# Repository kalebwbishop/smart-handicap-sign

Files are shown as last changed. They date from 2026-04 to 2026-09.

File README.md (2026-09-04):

# Hazard Hero

Hazard Hero is a **one-sign pilot** for accessible parking assistance. The pilot proves one simple loop:

1. A visitor waves at the installed sign.
2. The sign sends the configured sample window to the backend.
3. The backend marks the sign as `assistance_requested`.
4. A staff member sees the request in the app, acknowledges it, and resolves it.
5. The sign returns to `available`.

If a request turns out to be a false positive, the operator app can label it and the backend keeps the raw samples for later training.

If that loop works reliably for one installed sign, the pilot is successful.

## Pilot scope

### In scope

- One installed ESP32 sign
- One backend environment
- One operator account or one small pilot team
- One mobile operator workflow
- One fixed installation location
- Basic event history for request, acknowledge, and resolve actions

### Explicitly deferred

These items may exist elsewhere in the repo, but they are **not required for pilot launch**:

- Multi-org or fleet management workflows
- Rich site and parking-space administration
- Full QR/device claim operations for scaled deployment
- OTA update workflows
- Push notifications as a launch dependency
- Training-mode productization
- Old social/media/template features from earlier repo history

See `PILOT.md` for the detailed pilot definition and launch checklist.

## Pilot architecture

```text
ESP32 sign
  -> GET /api/v1/devices/{serial}/status
  -> when status == available, collect the configured ADC sample window
  -> POST /api/v1/inference/classify
  -> backend changes sign to assistance_requested when a wave is detected
  -> staff app shows the request
  -> staff acknowledges and resolves the request
```

Primary sign states for the pilot:

`available -> assistance_requested -> assistance_in_progress -> available`

## Repository layout

```text
smart-handicap-sign/
├── backend/      FastAPI API, async services, embedded inference
├── frontend/     React Native + Expo operator app
├── database/     PostgreSQL schema and migration scripts
├── firmware/     ESP-IDF firmware for the pilot sign
├── hardware/     Legacy MicroPython implementation
├── ai/           Model training code
└── PILOT.md      Pilot scope and launch checklist
```

## Quick start

### Prerequisites

- Node.js 18+
- Python 3.12 for the backend
- Docker Desktop
- PostgreSQL access via `docker compose`
- WorkOS credentials for auth

### Local setup

1. Install workspace dependencies:

   ```bash
   npm install
   ```

2. Configure environment variables:

   - `backend/.env`
   - `frontend/.env`

3. Start Postgres:

   ```bash
   npm run db:up
   ```

4. Apply the schema:

   ```bash
   npm run db:migrate
   ```

5. Run the backend:

   ```bash
   cd backend
   pip install -r requirements.txt
   uvicorn app.main:app --host 0.0.0.0 --port 8000 --reload
   ```

   To open a live matplotlib graph for every inference payload during local debugging,
   set `INFERENCE_DEBUG_PLOT_ENABLED=true` in `backend/.env` before starting the backend.

6. Run the frontend:

   ```bash
   cd frontend
   npm start
   ```

7. Flash and provision the pilot sign using `firmware/README.md`.

## Pilot operations

For the pilot, operators only need to:

1. Log in.
2. Watch the current sign status.
3. Acknowledge a new assistance request.
4. Resolve the request after helping the visitor.

Setup, manufacturing, and scale-out workflows should not be treated as launch blockers.

## Key API endpoints for the pilot

- `GET /health`
- `GET /api/v1/status`
- `GET /api/v1/devices/{serial_number}/status`
- `POST /api/v1/inference/classify`
- `POST /api/v1/devices/{serial_number}/acknowledge`
- `POST /api/v1/devices/{serial_number}/resolve`
- `POST /api/v1/devices/{serial_number}/events/{device_event_id}/false-positive`

## Validation

Useful repo commands for the pilot:

```bash
# Backend tests
cd backend
pytest

# Frontend lint
npm run lint --workspace=frontend

# Frontend tests (placeholder suite)
npm run test --workspace=frontend
```

Firmware validation depends on an ESP-IDF 5.4+ environment; see `firmware/README.md` and `firmware/TEST_PLAN.md`.

## Related docs

- `PILOT.md` - pilot definition and launch checklist
- `firmware/README.md` - flash, configure, and operate the pilot sign
- `firmware/TEST_PLAN.md` - hardware validation checklist for the pilot sign
- `WORKOS_SETUP.md` - auth provider setup

## Status

This repository still contains some post-pilot or legacy building blocks. When documentation and implementation disagree, treat the **one-sign pilot flow** as the current product target.

{
  "SchemaVersion": "1.0",
  "MessageId": "a4f2c8d1-6b73-4e95-9a20-1c5d7f8b3e42",
  "OccurredAt": "2026-09-02T20:20:00Z",
  "DeviceId": "SHS-2605-S01-A7K-00001-J",
  "Classification": {
    "Label": "positive",
    "Confidence": 0.97
  }
}

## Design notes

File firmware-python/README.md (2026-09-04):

## WS2812B LED test

This MicroPython test drives a 38-pixel WS2812B strip from an ESP32. It
alternates between solid green and off, holding each state for five seconds.

Default configuration:

- `LED_DATA_PINS`: usable output GPIOs tested one at a time
- `NUM_LEDS`: 38
- `BRIGHTNESS`: 128
- Color order: RGB values passed to MicroPython's `neopixel` driver

Copy `main.py` to the ESP32 as the runtime entry point. Connect the strip's
regulated 5 V and GND to the buck converter, connect ESP32 GND to the same
ground, and route the strip's `DIN` through a 330-470 ohm resistor to the GPIO currently
being tested. The firmware clears every strip before lighting the current pin.
A 1000 uF capacitor across the strip supply is recommended.

### Run on an ESP32

Install the host tools:

```powershell
python -m pip install esptool mpremote
```

Find the board's serial port in Windows Device Manager, then replace `COM3`
below if needed. For a fresh ESP32, download the generic firmware from
<https://micropython.org/download/ESP32_GENERIC/> and flash it:

```powershell
python -m esptool --port COM3 chip-id
python -m esptool --port COM3 erase-flash
python -m esptool --port COM3 --baud 460800 write-flash 0x1000 ESP32_GENERIC.bin
```

Copy the test to the board and restart it:

```powershell
python -m mpremote connect COM3 fs cp .\main.py :main.py
python -m mpremote connect COM3 reset
python -m mpremote connect COM3 repl
```

The test starts automatically after reset. Verify the deployed file with:

```powershell
python -m mpremote connect COM3 fs sha256sum :main.py
```
python -m mpremote connect COM3 fs cp .\main.py :main.py && python -m mpremote connect COM3 reset && python -m mpremote connect COM3 repl

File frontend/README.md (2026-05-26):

# frontend_new

This directory contains the new frontend monorepo structure for Hazard Hero.  
It separates mobile and web apps while sharing reusable code through workspace packages.

## Why `frontend_new` exists

`frontend_new` is an incremental migration target so we can:

1. Keep the old frontend flow untouched while migration is in progress.
2. Split platform apps cleanly (`apps/mobile`, `apps/web`).
3. Extract shared logic into packages (`packages/shared`, `packages/ui`).

## Directory layout

```text
frontend_new/
  apps/
    mobile/      # Expo React Native app
    web/         # Next.js web app
  packages/
    shared/      # shared types, API helpers, config utilities
    ui/          # shared UI package (scaffolded)
    eslint-config/
    tsconfig/
  package.json
  pnpm-workspace.yaml
  turbo.json
  tsconfig.base.json
```

## pnpm in this repo

This monorepo uses **pnpm workspaces**.

- Workspace manifest: `frontend_new/pnpm-workspace.yaml`
- Root package manager pin: `frontend_new/package.json` (`packageManager`)
- Cross-package deps use `workspace:*` (example: `@hazard-hero/shared`)

### Install dependencies

From `frontend_new`:

```bash
pnpm install
```

### Run apps

From `frontend_new`:

```bash
# Run all dev tasks via turbo
pnpm dev

# Run only mobile
pnpm dev:mobile

# Run only web
pnpm dev:web
```

### Useful workspace commands

```bash
# Typecheck all packages/apps through turbo
pnpm typecheck

# Run a command for one workspace package
pnpm --filter mobile lint
pnpm --filter web build
pnpm --filter @hazard-hero/shared typecheck
```

## Notes

- Run commands from inside `frontend_new` so pnpm resolves the workspace correctly.
- `apps/mobile` and `apps/web` can import from `packages/*`.
- `packages/*` must not import from `apps/*`.

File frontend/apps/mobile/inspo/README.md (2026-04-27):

# Composio Inspired Design System

[DESIGN.md](https://github.com/VoltAgent/awesome-design-md/blob/main/design-md/composio/DESIGN.md) extracted from the public [Composio](https://composio.dev/) website. This is not the official design system. Colors, fonts, and spacing may not be 100% accurate. But it's a good starting point for building something similar.

## Files

| File | Description |
|---|---|
| `DESIGN.md` | Complete design system documentation (9 sections) |
| `preview.html` | Interactive design token catalog (light) |
| `preview-dark.html` | Interactive design token catalog (dark) |

Use [DESIGN.md](https://github.com/VoltAgent/awesome-design-md/blob/main/design-md/composio/DESIGN.md) to use as a reference for AI agents (Claude, Cursor, Stitch) to generate UI that looks like the Composio design language.

## Preview

A sample landing page built with DESIGN.md. It shows the actual colors, typography, buttons, cards, spacing, and elevation, all in one page.

### Dark Mode
Composio Design System — Dark Mode

### Light Mode
Composio Design System — Light Mode

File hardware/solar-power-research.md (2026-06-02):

# Solar Power Feasibility Research - Hazard Hero Sign Node

> **Directory note:** The `hardware/` directory is legacy-designated in this repository; the
> active embedded implementation lives in `firmware/`. This document is placed here
> intentionally because it is most naturally read alongside the PCB design artifacts
> (`hazard-hero-easyeda-pcb.json`, `hazard-hero-pcb-README.md`) and the legacy MicroPython
> files (`main.py`, `config.py`, etc.) that preceded the current C firmware. All firmware
> citations reference the active ESP-IDF C codebase under `firmware/main/`.

---

## Executive Summary

The Hazard Hero sign node is presently designed for a hardwired **12 V DC** field supply. The
PCB includes a reserved battery header (J2/VBAT) but no charge controller, no power-path
management IC, and no battery management subsystem. The active firmware runs the ESP32-WROOM-32
at a fixed **240 MHz** with Wi-Fi continuously associated and no power management enabled - a
configuration optimized for deterministic latency, not energy efficiency.

The controller alone draws roughly **80-120 mA at 3.3 V** in the steady-state sampling loop,
before the sign or lamp load switched by Q1 is considered. Because that lamp load is
**not characterized anywhere in the repository**, any specific panel-watt or battery-Ah figure
would carry an order-of-magnitude uncertainty and is intentionally avoided in this document.
Rough sizing formulas are provided so the work can be completed once the lamp load is measured.

Solar operation is technically achievable on this platform, but it requires changes at every
layer: new PCB hardware (charge controller, power-path IC, battery connector), a redesigned
power entry section, firmware power-management strategy (DFS, modem-sleep, and graceful
offline behavior), and an enclosure-level survey for panel placement and thermal management.
None of these are present today. This document maps each gap, estimates the scope of work, and
identifies the highest-risk items to resolve before committing to a solar build.

---

## 1. Current Architecture Overview

### 1.1 PCB power chain

The Hazard Hero controller board (`hardware/hazard-hero-pcb-README.md`) implements a
straightforward cascade:[^pcb-flow]

```
J1 (12 V IN)
  -> F1 (PTC resettable fuse / current limit)
  -> D1 (TVS transient clamp)
  -> U1 (external 5 V buck module header)
  -> U2 (3.3 V SOT-223 LDO)
  -> U3 (ESP32 controller module)
```

The sign or lamp load is fed from the fused 12 V rail through J3 (`VIN_FUSED` / `LAMP_RET`)
and switched on the low side by the Q1 DPAK MOSFET. The load topology means Q1 carries the
full lamp current referenced to GND, while the supply side of the lamp sees the protected
12 V rail directly.

**J2 (VBAT)** is a reserved 2-pin terminal. The PCB README states explicitly: *"The current
layout does not yet include a full charger or power-path management circuit around it."*[^j2-vbat]
It is a provision point, not a functional battery subsystem.

### 1.2 Active firmware at a glance

| Item | Value | Source |
|---|---|---|
| Target module | ESP32-WROOM-32 (4 MB flash, no PSRAM) | `firmware/sdkconfig.defaults:2` (comment), `firmware/README.md:9` |
| CPU clock | **240 MHz, fixed** | `firmware/sdkconfig.defaults:10` |
| ADC batch size | **configured sample window** | `firmware/main/adc_sampler.h:10` |
| Sample interval | **configured interval** | `firmware/main/adc_sampler.h:11`, comment line 22 |
| Status poll interval | **3 s** (non-`available` states) | `firmware/main/main.c:25` |
| Post-classify inter-loop delay | **1 s** | `firmware/main/main.c:24` |
| Watchdog timeout | **30 s** | `firmware/sdkconfig.defaults:28` |
| Wi-Fi mode | STA, always-on | `firmware/main/wifi_manager.c` |
| Wi-Fi power saving | **None configured** | No `esp_wifi_set_ps()` call in codebase |
| ESP-IDF power management | **Not enabled** | `CONFIG_PM_ENABLE` absent from `firmware/sdkconfig.defaults` |

Main loop cycle when the device is in `available` state:[^main-loop]

```
poll GET /devices/{serial}/status
  -> if not available -> wait 3 s, loop
  -> if available:
       collect the configured ADC sample batch   (CPU mostly idle, Wi-Fi held live)
       POST /inference/classify
       wait 1 s
       loop
```

During the ADC window, the Wi-Fi association is maintained but no data is transmitted.
The CPU spends the vast majority of this window blocked inside `vTaskDelay(pdMS_TO_TICKS(25))`
between samples - idle time that power management could exploit if enabled.[^adc-loop]

### 1.3 Legacy MicroPython context

The `hardware/` directory contains legacy MicroPython files (`main.py`, `config.py`,
`led.py`, `provision.py`, `sensor.py`, `identity.py`, `wifi_utils.py`) that preceded the
current ESP-IDF C implementation. The firmware README explicitly states the C firmware
"replaces the legacy MicroPython runtime in `hardware/`".[^fw-readme] Those Python files are
historical artifacts; they are not executed by any active hardware.

---

## 2. What Would Need to Be Added for Solar Power

### 2.1 Solar input and charge regulation

No solar charging circuit exists on the current PCB. A production-grade addition requires at
minimum the following components, none of which are present:

1. **MPPT solar charge controller IC** - sits between the solar panel and the battery,
   maximizing panel power extraction while protecting the battery from overcharge and
   providing a stable output bus. Examples: Texas Instruments BQ24650 (lead-acid / LiFePO4
   compatible), CN3791 (simpler MPPT, single-cell lithium), or a module-level solution such
   as a Victron SmartSolar unit for higher powers.

2. **Battery pack** - a chemistry chosen for the outdoor temperature range. LiFePO4 (lithium
   iron phosphate) is strongly preferred for field use: better cycle life, flatter discharge
   curve, and safer thermal behavior than NMC/NCA. It requires a chemistry-appropriate
   charger and cell-level BMS (battery management system) for overdischarge protection.
   Sealed lead-acid (SLA / AGM) is a lower-cost alternative with lower energy density and
   more stringent temperature derating.

3. **Power-path / load switch** - a circuit that routes power from solar/battery to the
   system, prevents the battery from being pulled below a safe cut-off voltage during heavy
   load, and handles the transition gracefully when solar input drops at sunset. The J2 VBAT
   header has no such circuit.[^j2-vbat]

4. **Revised input voltage architecture** - the existing cascade assumes 12 V at J1. A
   LiFePO4 cell is nominally 3.2 V (12.8 V for a 4S pack). A 4S LiFePO4 pack is a
   workable fit for the existing 12 V input range, but the U1 buck and U2 LDO selection must
   be verified against the full charge/discharge voltage sweep (approximately 10.0-14.6 V for
   4S LiFePO4). A single-cell lithium or 12 V SLA pack could also be used with appropriate
   charge controller output configuration.

### 2.2 PCB redesign scope

The existing board is described as a **2-layer FR-4 concept design** not yet through full
schematic-capture review, footprint lock, or DRC/ERC cleanup.[^pcb-limits] The changes
needed for solar operation are substantial enough that they would produce a new board revision
rather than a rework of the current layout:

| Component / net | Current state | Solar addition required |
|---|---|---|
| J1 (12 V IN) | Mains or vehicle wiring | Battery output rail from charge controller |
| J2 (VBAT) | 2-pin reserved header, no circuit | Full charge IC, BMS, battery connector |
| U1 (5 V buck header) | External module placeholder | Verify input range vs battery sweep |
| U2 (3.3 V LDO) | Cascaded from 5 V | Unchanged if 5 V rail preserved; consider direct 3.3 V buck |
| Power-path IC | Absent | New IC footprint (ideal diode / load switch) |
| Charge controller IC | Absent | New IC footprint + MPPT sense resistors + passives |
| Battery fuel gauge | Absent | Optional but strongly recommended (I2C SOC readout) |
| Solar input TVS/EMI filter | Absent | Panel-side transient clamping, reverse-polarity protection |

The J4 sensor header exposes `I2C_SCL` on pin 3,[^j4-sensor] making it a natural attachment
point for a battery fuel-gauge IC (for example, Texas Instruments BQ27427 or Maxim MAX17048)
once the charge subsystem exists. No firmware or PCB changes to J4 itself are required to add
this peripheral.

---

## 3. Firmware Changes Required for Solar Viability

### 3.1 Enable ESP-IDF power management

`firmware/sdkconfig.defaults` does not contain `CONFIG_PM_ENABLE`, which is the gate for all
dynamic frequency scaling and automatic light-sleep on the ESP32.[^sdkconfig] Without it:

- The CPU is pinned at **240 MHz** at all times, including the 12.8 s ADC collection window
  when the processor is almost entirely idle inside `vTaskDelay()`.
- The Wi-Fi modem cannot enter sleep between beacon intervals.
- The APB bus remains at 80 MHz, holding peripheral clocks at maximum rate.

The minimum configuration additions:

```kconfig
# firmware/sdkconfig.defaults additions
CONFIG_PM_ENABLE=y
CONFIG_FREERTOS_USE_TICKLESS_IDLE=y   # required for automatic light-sleep
```

And in `app_main()` after Wi-Fi connects (`firmware/main/main.c`), a call to
`esp_pm_configure()` with appropriate `max_freq_mhz`, `min_freq_mhz`, and
`light_sleep_enable` fields, plus `esp_wifi_set_ps(WIFI_PS_MAX_MODEM)` (or `MIN_MODEM`)
after `wifi_sta_connect()` returns.[^esp-pm-docs]

### 3.2 Exploit idle time in the ADC collection window

`adc_sampler_collect_batch()` calls `vTaskDelay(pdMS_TO_TICKS(SAMPLE_INTERVAL_MS))` between
every pair of samples across the configured sample batch.[^adc-loop] During the batch window,
the CPU is inside a FreeRTOS idle delay for most of the interval. With `CONFIG_PM_ENABLE` and tickless idle enabled, FreeRTOS will automatically
place the chip into light-sleep during each 25 ms gap, potentially reducing the effective
current draw from approximately 80-120 mA to under 1 mA for those intervals. This alone could
cut the energy per inference cycle by a large fraction without any restructuring of
application logic.

For the status-poll idle path (3 s `vTaskDelay` when status != `available`), modem-sleep with
DTIM wakeup is appropriate: Wi-Fi power saving `WIFI_PS_MAX_MODEM` allows the radio to sleep
between access point beacon intervals while maintaining association.[^esp-pm-docs]

### 3.3 Fix the provisioning mode power-failure trap

When Wi-Fi reconnection fails `MAX_RECONNECT_FAILURES` (= 3) consecutive times, `app_main()`
calls `enter_provisioning_mode()`.[^reconnect] That function:

1. Calls `disable_task_wdt()` - permanently disabling the 30 s hardware watchdog.[^prov-wdt]
2. Starts SoftAP (beacon transmitted continuously at full RF power).
3. Starts the HTTP provisioning server.
4. Calls `halt_forever()` - an infinite `vTaskDelay(1000)` loop that **never exits and never
   sleeps**.[^halt]

In a mains-powered deployment this is an acceptable maintenance mode. On a battery-backed
solar node it is a latent **high-power drain with no exit path**: the device will run at full
radio power indefinitely, with no watchdog to recover from a firmware fault, until a technician
connects to the provisioning AP and enters credentials. If this happens at night or during
cloudy weather, the battery will discharge to cut-off.

Mitigations to implement before any solar deployment:

- Add a **provisioning timeout** (for example, 15-30 minutes). If no client connects, enter
  deep sleep for a configurable retry interval (for example, 30 minutes), then repeat. Log a
  `STATUS_OFFLINE` or provisioning event to NVS so the reason for the outage is recoverable on
  next boot.
- **Re-enable a watchdog** during provisioning (with a longer timeout, for example, 5 minutes)
  so that a firmware fault during the provisioning HTTP loop still triggers a reset.
- Consider a **maximum retry count** for the provisioning loop before the device gives up and
  enters long-interval deep sleep, requiring a manual reset to recover.

### 3.4 Add battery state-of-charge awareness

Solar operation requires the firmware to respond to battery level. At minimum:

- **Low-voltage shutdown path:** detect a battery voltage or SOC threshold below which
  continued operation would damage the cell. Enter deep sleep with a timer wakeup to
  periodically re-check whether solar charging has resumed. The ESP32-WROOM-32 supports
  deep sleep at approximately 10-150 uA depending on the wakeup source configured.

- **Reduced-function mode:** when SOC is low but above the shutdown threshold, skip the
  12.8 s ADC collection cycle (the highest sustained draw) and post a reduced-power status
  to the backend. Continue polling status at a low rate only.

- **SOC input signal:** the hardware signal can come from a fuel-gauge IC on J4's I2C bus
  (once the charger subsystem is added) or from a resistor-divider on the battery voltage
  read by a spare ADC channel. Neither exists today.

### 3.5 OTA energy gate

The OTA subsystem (`firmware/main/ota_update.c`) uses `esp_https_ota` to download a full
firmware binary over TLS - typically 200-400 kB at maximum Wi-Fi throughput. This is the
longest sustained high-current event in the firmware. On a solar-battery node:

- OTA should be gated on battery SOC exceeding a safe threshold (for example, > 60%).
- The existing rollback infrastructure (`esp_ota_mark_app_invalid_rollback_and_reboot()`) is
  an adequate recovery mechanism if a download is interrupted by a voltage drop.
- OTA should preferably be scheduled during daylight hours when solar input is active.

No OTA gating logic exists today; this is a new code path.

---

## 4. Sensor and Enclosure Considerations

### 4.1 Photoresistor and panel placement coupling

The firmware samples a photoresistor on **GPIO 34 / ADC1_CH6** as the primary inference
input.[^fw-readme] If the photoresistor and the solar panel are mounted on the same enclosure
face, the panel will shadow the sensor at certain sun angles, and specular reflections off
the panel surface may artificially elevate the sensor reading. Panel placement and sensor
orientation must be treated as coupled constraints in the enclosure mechanical design.

### 4.2 Operating temperature range

Sealed outdoor enclosures in direct sun routinely reach 60-80 C internally on summer days in
temperate climates, and higher in desert environments. Binding temperature limits for
candidate components:

| Component | Typical max operating temp |
|---|---|
| ESP32-WROOM-32 | 85 C |
| LiFePO4 cell (charge) | ~45-60 C (varies by cell) |
| LiFePO4 cell (discharge) | ~60-70 C (varies by cell) |
| Sealed lead-acid / AGM | ~50 C continuous |
| Standard electrolytic capacitors | 85-105 C rated |

LiFePO4 is likely the binding constraint. The enclosure thermal design must maintain internal
temperature within battery chemistry limits, or a thermostatically controlled charge cutoff
must be added.

### 4.3 Ingress protection and connector sealing

The PCB connectors (J1-J5) are standard terminal blocks and pin headers with no specified IP
rating.[^pcb-bom] An outdoor solar installation requires:

- Weatherproof cable entry at each field connector (conduit fittings or IP-rated cable glands).
- Consideration of condensation on the PCB, particularly around the antenna keep-out region
  on U3 where a conformal coating must not be applied.
- Panel cable routing that avoids UV degradation and mechanical abrasion at enclosure
  penetrations.

### 4.4 ESP32 vs ESP32-S3 module discrepancy

The PCB README describes U3 as an **"ESP32-S3 module area"**,[^pcb-u3] while the firmware
and `sdkconfig.defaults` target the **ESP32-WROOM-32** (an original ESP32, not S3). These
modules have different package footprints, pin layouts, and power profiles. This discrepancy
must be resolved before ordering any new PCB revision that also incorporates the solar charge
subsystem. Both modules are usable targets for this application; the choice affects both PCB
layout and the specific deep-sleep / ULP architecture available for power management.

---

## 5. Sizing Guidance and Caveats

> **Critical caveat - do not size without measuring the lamp load first.**
>
> The sign or lamp load switched by Q1 is not characterized anywhere in the repository.
> The PCB README flags load-current measurement as a prerequisite for fabrication review
> (item 6 of its "Important current limitations" section).[^pcb-limits] A 3 W LED retrofit
> lamp and a 20 W traditional sign lamp differ by nearly a factor of seven in daily energy
> consumption. At typical panel derating factors, that difference alone spans the gap between
> a 10 W panel and a 60 W panel. **Any specific Wp or Ah number given without this
> measurement is not actionable.**

### 5.1 Approximate controller power (baseline reference only)

The following figures are drawn from Espressif's ESP32-WROOM-32 datasheet and the ESP-IDF
power management documentation. They represent typical values; actual in-circuit measurements
on this PCB may differ due to LDO inefficiency, leakage paths, and peripheral loads.

| Firmware / hardware state | Approx. controller current at 3.3 V | Notes |
|---|---|---|
| Active, 240 MHz, Wi-Fi TX burst | 200-240 mA | Peak only; brief during classify POST |
| Active, 240 MHz, Wi-Fi associated, CPU idle | **80-120 mA** | **Dominant state in current firmware** |
| Modem-sleep, CPU active, DTIM wakeup | 20-30 mA | Requires `esp_wifi_set_ps()` |
| Light-sleep (tickless idle, radio off) | < 1 mA | Requires `CONFIG_PM_ENABLE` + tickless idle |
| Deep sleep, RTC timer wakeup | 0.01-0.15 mA | Low-battery / no-sun fallback target |

**System efficiency note:** The 3.3 V LDO (U2) drops 1.7 V from the 5 V rail. At 100 mA
controller draw this dissipates approximately 170 mW as heat and makes the 12 V -> 5 V -> 3.3 V
path roughly 50-55% efficient for the controller load alone. A solar-optimized board revision
should replace the LDO with a direct 3.3 V synchronous buck from the battery rail to recover
this efficiency.

### 5.2 Sizing framework - fill in with real measurements

Once the lamp load is measured, apply this framework:

```
Daily energy (Wh):
  E_day = (P_controller_meas + P_lamp_meas) x hours_per_day_active

Battery capacity (Ah at system voltage V_bat):
  C_bat = E_day x autonomy_days / (V_bat x DoD)

  DoD = 0.80 for LiFePO4 (80% depth of discharge)
  DoD = 0.50 for sealed lead-acid

Panel rated power (Wp):
  P_panel = E_day / (PSH x eta_derating)

  PSH  = peak sun hours per day (3-5 h/day, location-dependent)
  eta_derating ~= 0.75-0.80 for dust, tilt angle error, temperature, and wiring losses
```

**Illustrative controller-only example (no lamp, current always-on firmware):**
Assuming 100 mA average at 3.3 V is approximately 0.33 W at the logic rail, and accounting
for the cascaded power conversion efficiency (approximately 55%), the 12 V input draw is
roughly 0.6 W for the controller alone, or approximately 50 mA from the 12 V bus. Over
24 hours this is approximately 14 Wh. At 4 peak sun hours and 0.75 derating:
approximately 5 W panel. For 3 days of autonomy with LiFePO4 at 80% DoD:
approximately 5 Ah at 12 V. These numbers are for the **controller only** and will be dwarfed
by any non-trivial lamp load. They are included solely as a framework sanity check, not a
specification.

---

## 6. Biggest Risks

| Risk | Severity | Basis |
|---|---|---|
| **Unknown lamp load** | **Critical** | Dominates the energy budget; no characterization exists in the repo. Cannot finalize any solar design without this measurement. |
| **Provisioning mode becomes a battery-drain trap** | **High** | `halt_forever()` + SoftAP active + no watchdog + no timeout: a unit that loses Wi-Fi credentials in the field will drain a battery to cut-off with no recovery path.[^halt][^prov-wdt] |
| **No low-voltage shutdown in firmware** | **High** | No code path exists to detect battery depletion. Deep discharge of LiFePO4 causes permanent cell damage. Requires both new hardware signal and new firmware handling. |
| **LDO thermal dissipation in sealed enclosure** | **Medium** | 3.3 V LDO from 5 V wastes approximately 34% of controller power as heat. In a sealed enclosure under direct sun this compounds the thermal management challenge. |
| **PCB U3 module footprint mismatch** | **Medium** | PCB README says ESP32-S3; firmware targets ESP32-WROOM-32. Any new board revision must resolve this before layout. Incorrect footprint would make the board unfabricable or unpopulatable.[^pcb-u3] |
| **No power-path management on J2** | **Medium** | Battery can be physically connected via J2 but cannot be safely charged or discharged without a charger IC and load switch. The header alone is not a functional circuit.[^j2-vbat] |
| **Enclosure temperature vs battery chemistry** | **Medium** | Sealed outdoor enclosures can exceed LiFePO4 charge temperature limits (approximately 45-60 C) on hot days. |
| **Wi-Fi reconnect adds sustained high-power retries** | **Low-Medium** | Three failures -> provisioning mode; each failed attempt uses a 20 s blocking connect timeout (`WIFI_CONNECT_TIMEOUT_MS = 20000`), meaning up to 60 s of maximum-current Wi-Fi activity per reconnect cycle before the provisioning trap is entered.[^reconnect] |
| **OTA mid-download voltage drop** | **Low** | Rollback partition exists and is exercised; risk is manageable but OTA should be gated on battery SOC before enabling over-the-air updates on a solar node. |

---

## 7. Recommended Next Steps

Listed in approximate dependency order.

1. **Measure the lamp/sign load.** Attach a current probe to J3 `VIN_FUSED` / `LAMP_RET`
   under normal duty conditions. This single measurement unlocks all subsequent sizing
   decisions and is the highest-value action on this list.

2. **Characterize controller power in-circuit.** Instrument the 12 V input rail and the
   3.3 V rail under real firmware execution: during an ADC batch window, during a Wi-Fi POST,
   and during the 3 s status-poll idle period. Compare with the datasheet estimates in §5.1.

3. **Enable power management on a firmware development branch.** Add `CONFIG_PM_ENABLE=y`,
   `CONFIG_FREERTOS_USE_TICKLESS_IDLE=y`, call `esp_pm_configure()` in `app_main()`, and
   call `esp_wifi_set_ps(WIFI_PS_MAX_MODEM)` after the Wi-Fi connect. Measure the resulting
   current profile against the baseline from step 2 to quantify achievable savings before
   committing to any hardware changes.

4. **Fix the provisioning mode power sink.** Add a configurable provisioning timeout (for
   example, 15 minutes). After timeout: deep-sleep for a retry interval, log to NVS, re-enable
   a watchdog during provisioning. This is a firmware-only change with no hardware dependency.

5. **Resolve the ESP32 / ESP32-S3 footprint discrepancy.** Decide the target module for the
   next PCB revision and update whichever of the PCB layout or the firmware target is
   incorrect. This must be settled before any new board is ordered.

6. **Design the new PCB power section.** With real load numbers in hand (step 1), select:
   battery chemistry and voltage, charge controller IC, load switch / power-path IC, and
   input topology. Treat J2 as a placeholder to be replaced by a complete charge-management
   subsystem. Design the 3.3 V conversion to bypass the LDO in favor of a direct buck.

7. **Thermal survey of the candidate enclosure.** Place a data logger inside a sealed
   prototype enclosure in direct sun. Confirm that internal temperatures remain within battery
   chemistry charge limits and within the ESP32 operating range.

8. **Add battery SOC awareness to firmware.** Wire a voltage divider or fuel-gauge IC to
   give the firmware a battery level signal. Implement the low-voltage shutdown path and
   the reduced-function mode described in §3.4. Gate OTA on SOC.

---

## 8. Confidence Assessment

| Claim | Confidence | Basis |
|---|---|---|
| CPU fixed at 240 MHz, no power management | **Verified** | `firmware/sdkconfig.defaults:10` confirms `CONFIG_ESP_DEFAULT_CPU_FREQ_240=y`; `CONFIG_PM_ENABLE` is absent |
| ADC batch = configured sample window | **Verified** | `firmware/main/adc_sampler.h:10-11` and comment on line 22 |
| Wi-Fi always-on, no sleep policy | **Verified** | No `esp_wifi_set_ps()` call in `firmware/main/wifi_manager.c`; `CONFIG_PM_ENABLE` absent |
| Provisioning mode runs `halt_forever()` with WDT disabled | **Verified** | `firmware/main/main.c:36-40` (`halt_forever`), lines 43-53 (`disable_task_wdt`), lines 63-81 (`enter_provisioning_mode`) |
| J2 VBAT has no charger / power-path circuit | **Verified** | `hardware/hazard-hero-pcb-README.md:119` explicit statement |
| 12 V -> 5 V -> 3.3 V cascade | **Verified** | `hardware/hazard-hero-pcb-README.md:23-27` |
| PCB U3 labelled ESP32-S3; firmware targets WROOM-32 | **Verified** | `hardware/hazard-hero-pcb-README.md:48` vs `firmware/README.md:9` |
| Controller steady-state current 80-120 mA at 3.3 V | **Estimated** | Espressif datasheet typical values; not measured in-circuit on this specific board |
| LDO path efficiency approximately 50-55% | **Calculated** | Standard LDO behavior at stated voltages; actual depends on component selection and load |
| Rough sizing ranges in §5.2 | **Illustrative only** | Framework is sound; numbers depend entirely on lamp load measurement (unknown) |
| Lamp load contribution | **Unknown** | Not specified anywhere in the repository |

---

## Footnotes

[^pcb-flow]: `hardware/hazard-hero-pcb-README.md:23-28` - system-level power and signal
flow description.

[^j2-vbat]: `hardware/hazard-hero-pcb-README.md:119` - *"Reserved auxiliary or battery
connection point for future backup or ride-through support. The current layout does not yet
include a full charger or power-path management circuit around it."*

[^fw-readme]: `firmware/README.md:3-14` - confirms ESP32-WROOM-32 target, configured sample batch,
12.8 s window, GPIO 34 ADC input, GPIO 2 LED, and that this firmware replaces the legacy
MicroPython runtime in `hardware/`.

[^sdkconfig]: `firmware/sdkconfig.defaults:10` - `CONFIG_ESP_DEFAULT_CPU_FREQ_240=y`.
`CONFIG_PM_ENABLE` is absent from this file.

[^main-loop]: `firmware/main/main.c:274-332` - the `while(true)` main loop body. Constants
`STATUS_POLL_INTERVAL_MS=3000` (line 25), `SEND_INTERVAL_MS=1000` (line 24),
`MAX_RECONNECT_FAILURES=3` (line 27) defined at lines 23-29.

[^adc-loop]: `firmware/main/adc_sampler.c:89-107` - `adc_sampler_collect_batch()` loop;
`vTaskDelay(pdMS_TO_TICKS(SAMPLE_INTERVAL_MS))` called between every consecutive sample pair.

[^prov-wdt]: `firmware/main/main.c:43-53` - `disable_task_wdt()` calls
`esp_task_wdt_delete()` and `esp_task_wdt_deinit()`, permanently removing the watchdog.
Called unconditionally at line 67 inside `enter_provisioning_mode()`.

[^halt]: `firmware/main/main.c:36-40` - `halt_forever()` is an infinite
`while(true) { vTaskDelay(pdMS_TO_TICKS(1000)); }` loop.

[^reconnect]: `firmware/main/main.c:159-197` - `reconnect_wifi()` calls
`wifi_sta_connect(ssid, password, WIFI_CONNECT_TIMEOUT_MS)` where
`WIFI_CONNECT_TIMEOUT_MS=20000` (line 29). Up to `MAX_RECONNECT_FAILURES=3` attempts before
`enter_provisioning_mode()` is called.

[^pcb-bom]: `hardware/hazard-hero-pcb-README.md:86-103` - component reference table; no IP
or environmental ratings are listed for any connector.

[^pcb-limits]: `hardware/hazard-hero-pcb-README.md:212-226` - "Important current
limitations"; item 6 explicitly calls out output-stage load-current review as a prerequisite
for fabrication.

[^pcb-u3]: `hardware/hazard-hero-pcb-README.md:48` - describes U3 as *"ESP32-S3 module
area"*. `firmware/README.md:9` and `firmware/sdkconfig.defaults:2` (comment) both specify
ESP32-WROOM-32.

[^j4-sensor]: `hardware/hazard-hero-pcb-README.md:131-136` - J4 SENSOR header: pin 1 `3V3`,
pin 2 `SENSOR_IN`, pin 3 `I2C_SCL`, pin 4 `GND`.

[^esp-pm-docs]: ESP-IDF Power Management documentation (ESP32 target) -
<https://docs.espressif.com/projects/esp-idf/en/latest/esp32/api-reference/system/power_management.html>
- confirms `CONFIG_PM_ENABLE` is the prerequisite for DFS and automatic light-sleep, and that
`CONFIG_FREERTOS_USE_TICKLESS_IDLE` is required for automatic light-sleep to activate.

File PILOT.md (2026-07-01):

# Pilot checklist

This checklist is the launch gate for the **single-sign physical pilot**.

The pilot is ready only when the one-sign loop works end to end:

1. The sign boots.
2. The sign connects to Wi-Fi.
3. The sign polls backend status.
4. The sign samples the photoresistor only when status is `available`.
5. A real wave triggers `assistance_requested`.
6. The operator can acknowledge and resolve the request.
7. The system recovers after temporary Wi-Fi or backend loss.

## 1. Environment readiness

- [x] Backend environment is configured.
- [x] Frontend environment is configured.
- [x] Database connection string points at the pilot PostgreSQL instance.
- [x] WorkOS auth credentials are present.
- [ ] Pilot sign serial number and auth token are available.
- [ ] Pilot Wi-Fi credentials are available.
- [ ] Pilot backend URL includes `/api/v1`.
- [ ] TLS CA certificate matches the pilot backend chain.

## 2. Database readiness

- [ ] Pilot schema is applied cleanly.
- [ ] Seeded pilot device row exists.
- [ ] `device_events` stores request payloads and false-positive labels.
- [ ] `notifications`, `notification_preferences`, and `push_tokens` behave as expected for the pilot workflow.

## 3. Backend readiness

- [ ] `GET /health` returns healthy.
- [ ] `GET /api/v1/status` returns the API version and timestamp.
- [ ] `GET /api/v1/devices/{serial_number}/status` returns the installed sign state.
- [ ] `POST /api/v1/inference/classify` accepts the configured sample window.
- [ ] `POST /api/v1/devices/{serial_number}/acknowledge` transitions `assistance_requested` to `assistance_in_progress`.
- [ ] `POST /api/v1/devices/{serial_number}/resolve` returns the sign to `available`.
- [ ] `POST /api/v1/devices/{serial_number}/events/{device_event_id}/false-positive` marks false positives correctly.

## 4. Frontend readiness

- [ ] Operator can log in.
- [ ] Operator can see the pilot sign status.
- [ ] Operator can acknowledge a new assistance request.
- [ ] Operator can resolve a request after helping the visitor.
- [ ] Operator can mark a request as false positive.

## 5. Firmware readiness

- [ ] Firmware builds with ESP-IDF 5.4+.
- [ ] Firmware is flashed successfully to the installed ESP32.
- [ ] Device identity is preloaded or generated as expected.
- [ ] Wi-Fi provisioning works as recovery mode.
- [ ] Status polling works while connected to the pilot backend.
- [ ] LED patterns match backend state.
- [ ] Classification only runs when status is `available`.
- [ ] Device recovers after temporary Wi-Fi loss.

## 6. Physical installation readiness

- [ ] Sign is mounted at the pilot location.
- [ ] Power is stable.
- [ ] Wi-Fi coverage is strong enough at the install location.
- [ ] ADC/photoresistor wiring is correct.
- [ ] Operator can observe the sign and use the app during a live request.

## 7. Pilot validation run

- [ ] Run a boot test.
- [ ] Run a Wi-Fi reconnect test.
- [ ] Run a status poll test.
- [ ] Run a real wave detection test.
- [ ] Run an acknowledge/resolve test.
- [ ] Run a false-positive labeling test.
- [ ] Run a temporary backend outage test.
- [ ] Run a temporary Wi-Fi outage test.

## Go / no-go

**Go** only if every required checkbox above is complete and the live end-to-end loop works on the installed sign.

**No-go** if any of these still fail:

- boot or Wi-Fi provisioning
- backend status polling
- wave detection and classification
- acknowledge / resolve flow
- recovery from transient connectivity loss

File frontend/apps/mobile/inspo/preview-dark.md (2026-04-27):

<!DOCTYPE html>
<html lang="en">
<head>
<meta charset="UTF-8">
<meta name="viewport" content="width=device-width, initial-scale=1.0">
<title>Design System Preview: Composio (Dark)</title>
<link rel="preconnect" href="https://fonts.googleapis.com">
<link rel="preconnect" href="https://fonts.gstatic.com" crossorigin>
<link href="https://fonts.googleapis.com/css2?family=JetBrains+Mono:wght@400;500;700&display=swap" rel="stylesheet">
<style>
  :root {
    --color-white: #ffffff;
    --color-brand: #0007cd;
    --color-black: #000000;
    --color-void: #0f0f0f;
    --color-charcoal: #2c2c2c;
    --color-muted-smoke: #444444;
    --color-cyan: #00ffff;
    --color-signal-blue: #0089ff;
    --color-ocean-blue: #0096ff;
    --color-light-border: #e0e0e0;
    --ghost-white: rgba(255,255,255,0.6);
    --whisper-white: rgba(255,255,255,0.5);
    --phantom-white: rgba(255,255,255,0.2);
    --border-mist-12: rgba(255,255,255,0.12);
    --border-mist-10: rgba(255,255,255,0.10);
    --border-mist-08: rgba(255,255,255,0.08);
    --border-mist-06: rgba(255,255,255,0.06);
    --border-mist-04: rgba(255,255,255,0.04);
    --cyan-12: rgba(0,255,255,0.12);
    --font-sans: 'abcDiatype', ui-sans-serif, system-ui, -apple-system, BlinkMacSystemFont, 'Segoe UI', Roboto, sans-serif;
    --font-mono: 'JetBrains Mono', ui-monospace, SFMono-Regular, Menlo, Monaco, Consolas, monospace;
    /* Dark mode overrides */
    --page-bg: #000000;
    --surface: #0a0a0a;
    --card-bg: #050505;
  }

  * { margin: 0; padding: 0; box-sizing: border-box; }

  body {
    background: var(--page-bg);
    color: var(--color-white);
    font-family: var(--font-sans);
    font-size: 16px;
    line-height: 1.5;
    -webkit-font-smoothing: antialiased;
  }

  /* DARK MODE BADGE */
  .dark-badge {
    position: fixed;
    top: 16px;
    right: 16px;
    z-index: 200;
    background: var(--color-white);
    color: var(--color-black);
    font-family: var(--font-mono);
    font-size: 11px;
    font-weight: 500;
    text-transform: uppercase;
    letter-spacing: 0.55px;
    padding: 6px 14px;
    border-radius: 4px;
  }

  /* NAV */
  .nav {
    position: sticky;
    top: 0;
    z-index: 100;
    display: flex;
    align-items: center;
    justify-content: space-between;
    padding: 16px 40px;
    background: rgba(0,0,0,0.92);
    backdrop-filter: blur(12px);
    border-bottom: 1px solid var(--border-mist-04);
  }
  .nav-brand { font-size: 18px; font-weight: 500; letter-spacing: -0.3px; }
  .nav-links { display: flex; gap: 32px; align-items: center; }
  .nav-links a { color: var(--ghost-white); text-decoration: none; font-size: 14px; transition: color 0.2s; }
  .nav-links a:hover { color: var(--color-white); }
  .nav-cta {
    background: var(--color-white);
    color: var(--color-black);
    padding: 8px 20px;
    border: none;
    border-radius: 4px;
    font-size: 14px;
    font-family: var(--font-sans);
    font-weight: 500;
    cursor: pointer;
  }

  /* HERO */
  .hero {
    position: relative;
    text-align: center;
    padding: 120px 40px 100px;
    overflow: hidden;
  }
  .hero::before {
    content: '';
    position: absolute;
    top: 50%;
    left: 50%;
    width: 700px;
    height: 700px;
    transform: translate(-50%, -50%);
    background: radial-gradient(circle, rgba(0,7,205,0.3) 0%, rgba(0,255,255,0.1) 35%, transparent 65%);
    pointer-events: none;
  }
  .hero h1 {
    font-size: 64px;
    font-weight: 400;
    line-height: 0.87;
    letter-spacing: -1px;
    margin-bottom: 24px;
    position: relative;
  }
  .hero p {
    color: var(--ghost-white);
    font-size: 18px;
    line-height: 1.5;
    margin-bottom: 40px;
    position: relative;
  }
  .hero-buttons { display: flex; gap: 16px; justify-content: center; position: relative; }
  .btn-primary {
    background: var(--color-white);
    color: var(--color-black);
    padding: 10px 28px;
    border: none;
    border-radius: 4px;
    font-size: 16px;
    font-family: var(--font-sans);
    cursor: pointer;
  }
  .btn-cyan {
    background: var(--cyan-12);
    color: var(--color-white);
    padding: 10px 28px;
    border: 1px solid var(--color-ocean-blue);
    border-radius: 4px;
    font-size: 16px;
    font-family: var(--font-sans);
    cursor: pointer;
  }

  /* SECTIONS */
  .section {
    max-width: 1200px;
    margin: 0 auto;
    padding: 80px 40px;
  }
  .section-title {
    font-size: 13px;
    font-family: var(--font-mono);
    font-weight: 500;
    text-transform: uppercase;
    letter-spacing: 0.55px;
    color: var(--color-cyan);
    margin-bottom: 12px;
  }
  .section-heading {
    font-size: 40px;
    font-weight: 400;
    line-height: 1.0;
    margin-bottom: 48px;
  }
  .section-divider {
    border: none;
    border-top: 1px solid var(--border-mist-04);
    margin: 0 40px;
    max-width: 1200px;
    margin-left: auto;
    margin-right: auto;
  }

  /* COLOR PALETTE */
  .color-group { margin-bottom: 40px; }
  .color-group-title {
    font-size: 20px;
    font-weight: 500;
    line-height: 1.2;
    margin-bottom: 20px;
    color: var(--ghost-white);
  }
  .color-grid {
    display: grid;
    grid-template-columns: repeat(auto-fill, minmax(180px, 1fr));
    gap: 16px;
  }
  .color-swatch {
    border: 1px solid var(--border-mist-08);
    border-radius: 4px;
    overflow: hidden;
  }
  .color-swatch-block {
    height: 80px;
    position: relative;
  }
  .color-swatch-info {
    padding: 12px;
    background: var(--card-bg);
  }
  .color-swatch-name { font-size: 13px; font-weight: 500; margin-bottom: 2px; }
  .color-swatch-hex { font-family: var(--font-mono); font-size: 12px; color: var(--ghost-white); margin-bottom: 4px; }
  .color-swatch-role { font-size: 12px; color: var(--muted-smoke); line-height: 1.4; }

  /* TYPOGRAPHY */
  .type-sample { margin-bottom: 32px; padding-bottom: 32px; border-bottom: 1px solid var(--border-mist-04); }
  .type-sample:last-child { border-bottom: none; }
  .type-sample-text { margin-bottom: 8px; }
  .type-sample-label {
    font-family: var(--font-mono);
    font-size: 12px;
    color: var(--muted-smoke);
    letter-spacing: -0.24px;
  }

  /* BUTTONS */
  .button-row {
    display: flex;
    flex-wrap: wrap;
    gap: 20px;
    align-items: flex-start;
  }
  .button-demo { text-align: center; }
  .button-demo-label {
    font-family: var(--font-mono);
    font-size: 11px;
    color: var(--muted-smoke);
    margin-top: 10px;
    text-transform: uppercase;
    letter-spacing: 0.55px;
  }
  .btn-ghost-blue {
    background: transparent;
    color: var(--color-white);
    padding: 10px 24px;
    border: 1px solid var(--color-signal-blue);
    border-radius: 4px;
    font-size: 16px;
    font-family: var(--font-sans);
    cursor: pointer;
  }
  .btn-ghost-charcoal {
    background: transparent;
    color: var(--color-white);
    padding: 10px 24px;
    border: 1px solid var(--color-charcoal);
    border-radius: 4px;
    font-size: 16px;
    font-family: var(--font-sans);
    cursor: pointer;
  }
  .btn-phantom {
    background: var(--phantom-white);
    color: var(--whisper-white);
    padding: 10px 24px;
    border: none;
    border-radius: 4px;
    font-size: 16px;
    font-family: var(--font-sans);
    cursor: pointer;
  }

  /* CARDS */
  .card-grid { display: grid; grid-template-columns: repeat(auto-fit, minmax(300px, 1fr)); gap: 24px; }
  .card {
    background: var(--card-bg);
    border-radius: 4px;
    padding: 28px;
  }
  .card-standard { border: 1px solid var(--border-mist-08); }
  .card-brutalist {
    border: 1px solid var(--border-mist-08);
    box-shadow: 4px 4px 0px 0px rgba(0,0,0,0.4);
  }
  .card-glow {
    border: 1px solid var(--border-mist-08);
    box-shadow: 0px 8px 32px rgba(0,0,0,0.7);
    position: relative;
  }
  .card-glow::before {
    content: '';
    position: absolute;
    inset: -1px;
    border-radius: 4px;
    background: radial-gradient(ellipse at center, rgba(0,255,255,0.05) 0%, transparent 70%);
    pointer-events: none;
    z-index: 0;
  }
  .card h3 { font-size: 24px; font-weight: 500; line-height: 1.2; margin-bottom: 12px; position: relative; z-index: 1; }
  .card p { color: var(--ghost-white); font-size: 15px; line-height: 1.63; position: relative; z-index: 1; }
  .card-label {
    font-family: var(--font-mono);
    font-size: 11px;
    text-transform: uppercase;
    letter-spacing: 0.55px;
    color: var(--color-cyan);
    margin-bottom: 16px;
    position: relative;
    z-index: 1;
  }

  /* FORMS */
  .form-grid { display: grid; grid-template-columns: 1fr 1fr; gap: 24px; }
  .form-group { margin-bottom: 20px; }
  .form-label {
    display: block;
    font-size: 13px;
    font-weight: 500;
    margin-bottom: 8px;
    color: var(--ghost-white);
  }
  .form-input {
    width: 100%;
    padding: 10px 14px;
    background: transparent;
    border: 1px solid var(--border-mist-08);
    border-radius: 4px;
    color: var(--color-white);
    font-size: 16px;
    font-family: var(--font-sans);
    outline: none;
    transition: border-color 0.2s;
  }
  .form-input::placeholder { color: var(--whisper-white); }
  .form-input-focus { border-color: var(--color-signal-blue); }
  .form-input-error { border-color: #ff4444; }
  .form-error-text { font-size: 12px; color: #ff4444; margin-top: 6px; }
  textarea.form-input { min-height: 100px; resize: vertical; }

  /* SPACING */
  .spacing-row { display: flex; flex-wrap: wrap; gap: 12px; align-items: flex-end; }
  .spacing-item { text-align: center; }
  .spacing-box {
    background: var(--cyan-12);
    border: 1px solid rgba(0,255,255,0.2);
    border-radius: 2px;
    margin-bottom: 8px;
  }
  .spacing-label {
    font-family: var(--font-mono);
    font-size: 11px;
    color: var(--muted-smoke);
  }

  /* RADIUS */
  .radius-row { display: flex; flex-wrap: wrap; gap: 20px; align-items: center; }
  .radius-item { text-align: center; }
  .radius-box {
    width: 80px;
    height: 80px;
    background: var(--surface);
    border: 1px solid var(--border-mist-10);
    margin-bottom: 8px;
  }
  .radius-label {
    font-family: var(--font-mono);
    font-size: 11px;
    color: var(--muted-smoke);
  }
  .radius-context {
    font-size: 11px;
    color: var(--muted-smoke);
    margin-top: 2px;
  }

  /* ELEVATION */
  .elevation-grid { display: grid; grid-template-columns: repeat(auto-fit, minmax(220px, 1fr)); gap: 24px; }
  .elevation-card {
    background: var(--card-bg);
    border-radius: 4px;
    padding: 24px;
    min-height: 140px;
    display: flex;
    flex-direction: column;
    justify-content: space-between;
  }
  .elevation-flat { border: none; }
  .elevation-contained { border: 1px solid var(--border-mist-04); }
  .elevation-standard { border: 1px solid var(--border-mist-08); }
  .elevation-brutalist {
    border: 1px solid var(--border-mist-08);
    box-shadow: 4px 4px 0px 0px rgba(0,0,0,0.4);
  }
  .elevation-floating {
    border: 1px solid var(--border-mist-08);
    box-shadow: 0px 8px 32px rgba(0,0,0,0.7);
  }
  .elevation-name { font-size: 16px; font-weight: 500; margin-bottom: 8px; }
  .elevation-desc { font-size: 13px; color: var(--ghost-white); line-height: 1.5; }
  .elevation-level {
    font-family: var(--font-mono);
    font-size: 11px;
    color: var(--color-cyan);
    text-transform: uppercase;
    letter-spacing: 0.55px;
    margin-top: 12px;
  }

  /* RESPONSIVE */
  @media (max-width: 768px) {
    .nav { padding: 12px 20px; }
    .nav-links a:not(.nav-cta-wrapper) { display: none; }
    .hero { padding: 80px 20px 60px; }
    .hero h1 { font-size: 36px; }
    .section { padding: 60px 20px; }
    .section-heading { font-size: 28px; }
    .color-grid { grid-template-columns: repeat(auto-fill, minmax(140px, 1fr)); }
    .form-grid { grid-template-columns: 1fr; }
    .card-grid { grid-template-columns: 1fr; }
    .hero-buttons { flex-direction: column; align-items: center; }
    .button-row { flex-direction: column; align-items: flex-start; }
    .dark-badge { top: auto; bottom: 16px; right: 16px; }
  }
</style>
</head>
<body>

<!-- DARK MODE BADGE -->
<div class="dark-badge">Dark Mode</div>

<!-- NAV -->
<nav class="nav">
  <div class="nav-brand">Composio</div>
  <div class="nav-links">
    <a href="#colors">Colors</a>
    <a href="#typography">Typography</a>
    <a href="#buttons">Buttons</a>
    <a href="#cards">Cards</a>
    <a href="#forms">Forms</a>
    <a href="#spacing">Spacing</a>
    <a href="#elevation">Elevation</a>
    <button class="nav-cta">Get Started</button>
  </div>
</nav>

<!-- HERO -->
<section class="hero">
  <h1>Design System Preview:<br>Composio</h1>
  <p>Auto-generated design token catalog from DESIGN.md &mdash; Dark Mode</p>
  <div class="hero-buttons">
    <button class="btn-primary">Explore Tokens</button>
    <button class="btn-cyan">View Source</button>
  </div>
</section>

<hr class="section-divider">

<!-- COLORS -->
<section class="section" id="colors">
  <div class="section-title">01 / Color Palette</div>
  <h2 class="section-heading">Color Palette & Roles</h2>

  <div class="color-group">
    <h3 class="color-group-title">Primary</h3>
    <div class="color-grid">
      <div class="color-swatch">
        
        <div class="color-swatch-info">
          <div class="color-swatch-name">Composio Cobalt</div>
          <div class="color-swatch-hex">#0007cd</div>
          <div class="color-swatch-role">Core brand color for high-priority interactive elements</div>
        </div>
      </div>
    </div>
  </div>

  <div class="color-group">
    <h3 class="color-group-title">Secondary & Accent</h3>
    <div class="color-grid">
      <div class="color-swatch">
        
        <div class="color-swatch-info">
          <div class="color-swatch-name">Electric Cyan</div>
          <div class="color-swatch-hex">#00ffff</div>
          <div class="color-swatch-role">Attention-grabbing accent for glows and highlights</div>
        </div>
      </div>
      <div class="color-swatch">
        
        <div class="color-swatch-info">
          <div class="color-swatch-name">Signal Blue</div>
          <div class="color-swatch-hex">#0089ff</div>
          <div class="color-swatch-role">Button borders and interactive focus states</div>
        </div>
      </div>
      <div class="color-swatch">
        
        <div class="color-swatch-info">
          <div class="color-swatch-name">Ocean Blue</div>
          <div class="color-swatch-hex">#0096ff</div>
          <div class="color-swatch-role">CTA button accent borders</div>
        </div>
      </div>
    </div>
  </div>

  <div class="color-group">
    <h3 class="color-group-title">Surface & Background</h3>
    <div class="color-grid">
      <div class="color-swatch">
        
        <div class="color-swatch-info">
          <div class="color-swatch-name">Pure Black</div>
          <div class="color-swatch-hex">#000000</div>
          <div class="color-swatch-role">Dark mode page background</div>
        </div>
      </div>
      <div class="color-swatch">
        
        <div class="color-swatch-info">
          <div class="color-swatch-name">Void Black</div>
          <div class="color-swatch-hex">#0f0f0f</div>
          <div class="color-swatch-role">Standard page background</div>
        </div>
      </div>
      <div class="color-swatch">
        
        <div class="color-swatch-info">
          <div class="color-swatch-name">Charcoal</div>
          <div class="color-swatch-hex">#2c2c2c</div>
          <div class="color-swatch-role">Secondary button borders and dividers</div>
        </div>
      </div>
    </div>
  </div>

  <div class="color-group">
    <h3 class="color-group-title">Neutrals & Text</h3>
    <div class="color-grid">
      <div class="color-swatch">
        
        <div class="color-swatch-info">
          <div class="color-swatch-name">Pure White</div>
          <div class="color-swatch-hex">#ffffff</div>
          <div class="color-swatch-role">Primary headings and high-emphasis text</div>
        </div>
      </div>
      <div class="color-swatch">
        
        <div class="color-swatch-info">
          <div class="color-swatch-name">Muted Smoke</div>
          <div class="color-swatch-hex">#444444</div>
          <div class="color-swatch-role">De-emphasized body text, metadata</div>
        </div>
      </div>
      <div class="color-swatch">
        
        <div class="color-swatch-info">
          <div class="color-swatch-name">Ghost White</div>
          <div class="color-swatch-hex">rgba(255,255,255,0.6)</div>
          <div class="color-swatch-role">Secondary body text and link labels</div>
        </div>
      </div>
      <div class="color-swatch">
        
        <div class="color-swatch-info">
          <div class="color-swatch-name">Whisper White</div>
          <div class="color-swatch-hex">rgba(255,255,255,0.5)</div>
          <div class="color-swatch-role">Tertiary button text and placeholders</div>
        </div>
      </div>
      <div class="color-swatch">
        
        <div class="color-swatch-info">
          <div class="color-swatch-name">Phantom White</div>
          <div class="color-swatch-hex">rgba(255,255,255,0.2)</div>
          <div class="color-swatch-role">Subtle button backgrounds and receded UI</div>
        </div>
      </div>
    </div>
  </div>

  <div class="color-group">
    <h3 class="color-group-title">Border System</h3>
    <div class="color-grid">
      <div class="color-swatch">
        <div class="color-swatch-block" style="background: var(--page-bg); display: flex; align-items: center; justify-content: center;"></div>
        <div class="color-swatch-info">
          <div class="color-swatch-name">Border Mist 12</div>
          <div class="color-swatch-hex">rgba(255,255,255,0.12)</div>
          <div class="color-swatch-role">Prominent card edges, content separators</div>
        </div>
      </div>
      <div class="color-swatch">
        <div class="color-swatch-block" style="background: var(--page-bg); display: flex; align-items: center; justify-content: center;"></div>
        <div class="color-swatch-info">
          <div class="color-swatch-name">Border Mist 10</div>
          <div class="color-swatch-hex">rgba(255,255,255,0.10)</div>
          <div class="color-swatch-role">Standard container borders</div>
        </div>
      </div>
      <div class="color-swatch">
        <div class="color-swatch-block" style="background: var(--page-bg); display: flex; align-items: center; justify-content: center;"></div>
        <div class="color-swatch-info">
          <div class="color-swatch-name">Border Mist 06</div>
          <div class="color-swatch-hex">rgba(255,255,255,0.06)</div>
          <div class="color-swatch-role">Section dividers, subtle groupings</div>
        </div>
      </div>
      <div class="color-swatch">
        <div class="color-swatch-block" style="background: var(--page-bg); display: flex; align-items: center; justify-content: center;"></div>
        <div class="color-swatch-info">
          <div class="color-swatch-name">Border Mist 04</div>
          <div class="color-swatch-hex">rgba(255,255,255,0.04)</div>
          <div class="color-swatch-role">Faintest atmospheric separation</div>
        </div>
      </div>
    </div>
  </div>
</section>

<hr class="section-divider">

<!-- TYPOGRAPHY -->
<section class="section" id="typography">
  <div class="section-title">02 / Typography Scale</div>
  <h2 class="section-heading">Typography Rules</h2>

  <div class="type-sample">
    <div class="type-sample-text" style="font-size: 64px; font-weight: 400; line-height: 0.87;">Display Hero</div>
    <div class="type-sample-label">Display / Hero &mdash; 64px / 400 / 0.87 / normal &mdash; abcDiatype</div>
  </div>

  <div class="type-sample">
    <div class="type-sample-text" style="font-size: 48px; font-weight: 400; line-height: 1.0;">Section Heading</div>
    <div class="type-sample-label">Section Heading &mdash; 48px / 400 / 1.00 / normal &mdash; abcDiatype</div>
  </div>

  <div class="type-sample">
    <div class="type-sample-text" style="font-size: 40px; font-weight: 400; line-height: 1.0;">Sub-heading Large</div>
    <div class="type-sample-label">Sub-heading Large &mdash; 40px / 400 / 1.00 / normal &mdash; abcDiatype</div>
  </div>

  <div class="type-sample">
    <div class="type-sample-text" style="font-size: 28px; font-weight: 400; line-height: 1.2;">Sub-heading</div>
    <div class="type-sample-label">Sub-heading &mdash; 28px / 400 / 1.20 / normal &mdash; abcDiatype</div>
  </div>

  <div class="type-sample">
    <div class="type-sample-text" style="font-size: 24px; font-weight: 500; line-height: 1.2;">Card Title</div>
    <div class="type-sample-label">Card Title &mdash; 24px / 500 / 1.20 / normal &mdash; abcDiatype</div>
  </div>

  <div class="type-sample">
    <div class="type-sample-text" style="font-size: 20px; font-weight: 500; line-height: 1.2;">Feature Label</div>
    <div class="type-sample-label">Feature Label &mdash; 20px / 500 / 1.20 / normal &mdash; abcDiatype</div>
  </div>

  <div class="type-sample">
    <div class="type-sample-text" style="font-size: 18px; font-weight: 400; line-height: 1.2;">Body Large</div>
    <div class="type-sample-label">Body Large &mdash; 18px / 400 / 1.20 / normal &mdash; abcDiatype</div>
  </div>

  <div class="type-sample">
    <div class="type-sample-text" style="font-size: 16px; font-weight: 400; line-height: 1.5;">Body / Button Text</div>
    <div class="type-sample-label">Body / Button &mdash; 16px / 400 / 1.50 / normal &mdash; abcDiatype</div>
  </div>

  <div class="type-sample">
    <div class="type-sample-text" style="font-size: 15px; font-weight: 400; line-height: 1.63;">Body Small &mdash; used for longer-form content blocks</div>
    <div class="type-sample-label">Body Small &mdash; 15px / 400 / 1.63 / normal &mdash; abcDiatype</div>
  </div>

  <div class="type-sample">
    <div class="type-sample-text" style="font-size: 14px; font-weight: 400; line-height: 1.63; color: var(--ghost-white);">Caption text for descriptions and metadata</div>
    <div class="type-sample-label">Caption &mdash; 14px / 400 / 1.63 / normal &mdash; abcDiatype</div>
  </div>

  <div class="type-sample">
    <div class="type-sample-text" style="font-size: 13px; font-weight: 500; line-height: 1.5;">Label Text</div>
    <div class="type-sample-label">Label &mdash; 13px / 500 / 1.50 / normal &mdash; abcDiatype</div>
  </div>

  <div class="type-sample">
    <div class="type-sample-text" style="font-size: 12px; font-weight: 500; line-height: 1.0; text-transform: uppercase; letter-spacing: 0.3px;">TAG / OVERLINE</div>
    <div class="type-sample-label">Tag / Overline &mdash; 12px / 500 / 1.00 / 0.3px / uppercase &mdash; abcDiatype</div>
  </div>

  <div class="type-sample">
    <div class="type-sample-text" style="font-family: var(--font-mono); font-size: 16px; font-weight: 400; line-height: 1.5; letter-spacing: -0.32px;">const agent = composio.create({ tools: ["github", "slack"] })</div>
    <div class="type-sample-label">Code Body &mdash; 16px / 400 / 1.50 / -0.32px &mdash; JetBrains Mono</div>
  </div>

  <div class="type-sample">
    <div class="type-sample-text" style="font-family: var(--font-mono); font-size: 14px; font-weight: 400; line-height: 1.5; letter-spacing: -0.28px;">npx composio-cli init --framework langchain</div>
    <div class="type-sample-label">Code Small &mdash; 14px / 400 / 1.50 / -0.28px &mdash; JetBrains Mono</div>
  </div>

  <div class="type-sample">
    <div class="type-sample-text" style="font-family: var(--font-mono); font-size: 12px; font-weight: 400; line-height: 1.5; letter-spacing: -0.28px;">import { Composio } from "composio-core"</div>
    <div class="type-sample-label">Code Caption &mdash; 12px / 400 / 1.50 / -0.28px &mdash; JetBrains Mono</div>
  </div>

  <div class="type-sample">
    <div class="type-sample-text" style="font-family: var(--font-mono); font-size: 14px; font-weight: 400; line-height: 1.43; text-transform: uppercase; letter-spacing: 0.7px;">CODE OVERLINE</div>
    <div class="type-sample-label">Code Overline &mdash; 14px / 400 / 1.43 / 0.7px / uppercase &mdash; JetBrains Mono</div>
  </div>

  <div class="type-sample">
    <div class="type-sample-text" style="font-family: var(--font-mono); font-size: 11px; font-weight: 400; line-height: 1.33; text-transform: uppercase; letter-spacing: 0.55px;">CODE MICRO TAG</div>
    <div class="type-sample-label">Code Micro &mdash; 11px / 400 / 1.33 / 0.55px / uppercase &mdash; JetBrains Mono</div>
  </div>
</section>

<hr class="section-divider">

<!-- BUTTONS -->
<section class="section" id="buttons">
  <div class="section-title">03 / Button Variants</div>
  <h2 class="section-heading">Buttons</h2>

  <div class="button-row">
    <div class="button-demo">
      <button class="btn-primary">Get Started</button>
      <div class="button-demo-label">Primary / White Fill</div>
    </div>
    <div class="button-demo">
      <button class="btn-cyan">View Docs</button>
      <div class="button-demo-label">Cyan Accent CTA</div>
    </div>
    <div class="button-demo">
      <button class="btn-ghost-blue">Learn More</button>
      <div class="button-demo-label">Ghost / Signal Blue</div>
    </div>
    <div class="button-demo">
      <button class="btn-ghost-charcoal">Secondary</button>
      <div class="button-demo-label">Ghost / Charcoal</div>
    </div>
    <div class="button-demo">
      <button class="btn-phantom">Dismiss</button>
      <div class="button-demo-label">Phantom</div>
    </div>
  </div>
</section>

<hr class="section-divider">

<!-- CARDS -->
<section class="section" id="cards">
  <div class="section-title">04 / Card Examples</div>
  <h2 class="section-heading">Cards & Containers</h2>

  <div class="card-grid">
    <div class="card card-standard">
      <div class="card-label">Standard Card</div>
      <h3>Border Mist 08</h3>
      <p>Standard content card with subtle white border at 8% opacity on pure black surface. Deeper darkness for the dark mode variant.</p>
    </div>
    <div class="card card-brutalist">
      <div class="card-label">Brutalist Shadow</div>
      <h3>Hard Offset 4px</h3>
      <p>Hard-offset shadow intensified to 40% opacity on pure black. The brutalist personality cuts deeper against the absolute dark.</p>
    </div>
    <div class="card card-glow">
      <div class="card-label">Floating + Glow</div>
      <h3>Cyan Glow Halo</h3>
      <p>Soft diffuse shadow at 70% opacity with restrained cyan glow. The deeper black makes the glow more pronounced.</p>
    </div>
  </div>
</section>

<hr class="section-divider">

<!-- FORMS -->
<section class="section" id="forms">
  <div class="section-title">05 / Form Elements</div>
  <h2 class="section-heading">Inputs & Forms</h2>

  <div class="form-grid">
    <div>
      <div class="form-group">
        <label class="form-label">Default Input</label>
        <input type="text" class="form-input" placeholder="Enter your API key...">
      </div>
      <div class="form-group">
        <label class="form-label">Focus State</label>
        <input type="text" class="form-input form-input-focus" value="composio-api-key-xxxxx">
      </div>
      <div class="form-group">
        <label class="form-label">Error State</label>
        <input type="text" class="form-input form-input-error" value="invalid-key">
        <div class="form-error-text">Invalid API key format</div>
      </div>
    </div>
    <div>
      <div class="form-group">
        <label class="form-label">Textarea</label>
        <textarea class="form-input" placeholder="Describe your agent's task..."></textarea>
      </div>
    </div>
  </div>
</section>

<hr class="section-divider">

<!-- SPACING -->
<section class="section" id="spacing">
  <div class="section-title">06 / Spacing Scale</div>
  <h2 class="section-heading">Spacing System</h2>
  <p style="color: var(--ghost-white); margin-bottom: 32px;">Base unit: 8px. Scale builds from 1px to 40px.</p>

  <div class="spacing-row">
    <div class="spacing-item">
      
      <div class="spacing-label">1px</div>
    </div>
    <div class="spacing-item">
      
      <div class="spacing-label">2px</div>
    </div>
    <div class="spacing-item">
      
      <div class="spacing-label">4px</div>
    </div>
    <div class="spacing-item">
      
      <div class="spacing-label">6px</div>
    </div>
    <div class="spacing-item">
      
      <div class="spacing-label">8px</div>
    </div>
    <div class="spacing-item">
      
      <div class="spacing-label">10px</div>
    </div>
    <div class="spacing-item">
      
      <div class="spacing-label">12px</div>
    </div>
    <div class="spacing-item">
      
      <div class="spacing-label">14px</div>
    </div>
    <div class="spacing-item">
      
      <div class="spacing-label">16px</div>
    </div>
    <div class="spacing-item">
      
      <div class="spacing-label">18px</div>
    </div>
    <div class="spacing-item">
      
      <div class="spacing-label">20px</div>
    </div>
    <div class="spacing-item">
      
      <div class="spacing-label">24px</div>
    </div>
    <div class="spacing-item">
      
      <div class="spacing-label">30px</div>
    </div>
    <div class="spacing-item">
      
      <div class="spacing-label">32px</div>
    </div>
    <div class="spacing-item">
      
      <div class="spacing-label">40px</div>
    </div>
  </div>
</section>

<hr class="section-divider">

<!-- BORDER RADIUS -->
<section class="section">
  <div class="section-title">07 / Border Radius Scale</div>
  <h2 class="section-heading">Border Radius</h2>

  <div class="radius-row">
    <div class="radius-item">
      
      <div class="radius-label">0px</div>
      <div class="radius-context">Sharp / None</div>
    </div>
    <div class="radius-item">
      
      <div class="radius-label">2px</div>
      <div class="radius-context">Nearly squared</div>
    </div>
    <div class="radius-item">
      
      <div class="radius-label">4px</div>
      <div class="radius-context">Subtly rounded</div>
    </div>
    <div class="radius-item">
      
      <div class="radius-label">37px</div>
      <div class="radius-context">Pill-shaped</div>
    </div>
    <div class="radius-item">
      
      <div class="radius-label">9999px</div>
      <div class="radius-context">Full round</div>
    </div>
  </div>
</section>

<hr class="section-divider">

<!-- ELEVATION -->
<section class="section" id="elevation">
  <div class="section-title">08 / Elevation & Depth</div>
  <h2 class="section-heading">Depth & Elevation</h2>

  <div class="elevation-grid">
    <div class="elevation-card elevation-flat">
      <div>
        <div class="elevation-name">Flat</div>
        <div class="elevation-desc">No shadow, no border. Page background and inline text.</div>
      </div>
      <div class="elevation-level">Level 0</div>
    </div>
    <div class="elevation-card elevation-contained">
      <div>
        <div class="elevation-name">Contained</div>
        <div class="elevation-desc">Border Mist 04. Background groupings, subtle sections.</div>
      </div>
      <div class="elevation-level">Level 1</div>
    </div>
    <div class="elevation-card elevation-standard">
      <div>
        <div class="elevation-name">Card</div>
        <div class="elevation-desc">Border Mist 08. Standard content cards, code blocks.</div>
      </div>
      <div class="elevation-level">Level 2</div>
    </div>
    <div class="elevation-card elevation-brutalist">
      <div>
        <div class="elevation-name">Brutalist</div>
        <div class="elevation-desc">Hard offset shadow (4px 4px, 40% black). Distinctive feature highlights.</div>
      </div>
      <div class="elevation-level">Level 3</div>
    </div>
    <div class="elevation-card elevation-floating">
      <div>
        <div class="elevation-name">Floating</div>
        <div class="elevation-desc">Soft diffuse shadow (0px 8px 32px, 70% black). Modals, overlays.</div>
      </div>
      <div class="elevation-level">Level 4</div>
    </div>
  </div>
</section>

</body>
</html>

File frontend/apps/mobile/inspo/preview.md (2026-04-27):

<!DOCTYPE html>
<html lang="en">
<head>
<meta charset="UTF-8">
<meta name="viewport" content="width=device-width, initial-scale=1.0">
<title>Design System Preview: Composio</title>
<link rel="preconnect" href="https://fonts.googleapis.com">
<link rel="preconnect" href="https://fonts.gstatic.com" crossorigin>
<link href="https://fonts.googleapis.com/css2?family=JetBrains+Mono:wght@400;500;700&display=swap" rel="stylesheet">
<style>
  :root {
    --color-white: #ffffff;
    --color-brand: #0007cd;
    --color-black: #000000;
    --color-void: #0f0f0f;
    --color-charcoal: #2c2c2c;
    --color-muted-smoke: #444444;
    --color-cyan: #00ffff;
    --color-signal-blue: #0089ff;
    --color-ocean-blue: #0096ff;
    --color-light-border: #e0e0e0;
    --ghost-white: rgba(255,255,255,0.6);
    --whisper-white: rgba(255,255,255,0.5);
    --phantom-white: rgba(255,255,255,0.2);
    --border-mist-12: rgba(255,255,255,0.12);
    --border-mist-10: rgba(255,255,255,0.10);
    --border-mist-08: rgba(255,255,255,0.08);
    --border-mist-06: rgba(255,255,255,0.06);
    --border-mist-04: rgba(255,255,255,0.04);
    --cyan-12: rgba(0,255,255,0.12);
    --font-sans: 'abcDiatype', ui-sans-serif, system-ui, -apple-system, BlinkMacSystemFont, 'Segoe UI', Roboto, sans-serif;
    --font-mono: 'JetBrains Mono', ui-monospace, SFMono-Regular, Menlo, Monaco, Consolas, monospace;
  }

  * { margin: 0; padding: 0; box-sizing: border-box; }

  body {
    background: var(--color-void);
    color: var(--color-white);
    font-family: var(--font-sans);
    font-size: 16px;
    line-height: 1.5;
    -webkit-font-smoothing: antialiased;
  }

  /* NAV */
  .nav {
    position: sticky;
    top: 0;
    z-index: 100;
    display: flex;
    align-items: center;
    justify-content: space-between;
    padding: 16px 40px;
    background: rgba(15,15,15,0.92);
    backdrop-filter: blur(12px);
    border-bottom: 1px solid var(--border-mist-06);
  }
  .nav-brand { font-size: 18px; font-weight: 500; letter-spacing: -0.3px; }
  .nav-links { display: flex; gap: 32px; align-items: center; }
  .nav-links a { color: var(--ghost-white); text-decoration: none; font-size: 14px; transition: color 0.2s; }
  .nav-links a:hover { color: var(--color-white); }
  .nav-cta {
    background: var(--color-white);
    color: var(--color-void);
    padding: 8px 20px;
    border: none;
    border-radius: 4px;
    font-size: 14px;
    font-family: var(--font-sans);
    font-weight: 500;
    cursor: pointer;
  }

  /* HERO */
  .hero {
    position: relative;
    text-align: center;
    padding: 120px 40px 100px;
    overflow: hidden;
  }
  .hero::before {
    content: '';
    position: absolute;
    top: 50%;
    left: 50%;
    width: 600px;
    height: 600px;
    transform: translate(-50%, -50%);
    background: radial-gradient(circle, rgba(0,7,205,0.25) 0%, rgba(0,255,255,0.08) 40%, transparent 70%);
    pointer-events: none;
  }
  .hero h1 {
    font-size: 64px;
    font-weight: 400;
    line-height: 0.87;
    letter-spacing: -1px;
    margin-bottom: 24px;
    position: relative;
  }
  .hero p {
    color: var(--ghost-white);
    font-size: 18px;
    line-height: 1.5;
    margin-bottom: 40px;
    position: relative;
  }
  .hero-buttons { display: flex; gap: 16px; justify-content: center; position: relative; }
  .btn-primary {
    background: var(--color-white);
    color: var(--color-void);
    padding: 10px 28px;
    border: none;
    border-radius: 4px;
    font-size: 16px;
    font-family: var(--font-sans);
    cursor: pointer;
  }
  .btn-cyan {
    background: var(--cyan-12);
    color: var(--color-white);
    padding: 10px 28px;
    border: 1px solid var(--color-ocean-blue);
    border-radius: 4px;
    font-size: 16px;
    font-family: var(--font-sans);
    cursor: pointer;
  }

  /* SECTIONS */
  .section {
    max-width: 1200px;
    margin: 0 auto;
    padding: 80px 40px;
  }
  .section-title {
    font-size: 13px;
    font-family: var(--font-mono);
    font-weight: 500;
    text-transform: uppercase;
    letter-spacing: 0.55px;
    color: var(--color-cyan);
    margin-bottom: 12px;
  }
  .section-heading {
    font-size: 40px;
    font-weight: 400;
    line-height: 1.0;
    margin-bottom: 48px;
  }
  .section-divider {
    border: none;
    border-top: 1px solid var(--border-mist-06);
    margin: 0 40px;
    max-width: 1200px;
    margin-left: auto;
    margin-right: auto;
  }

  /* COLOR PALETTE */
  .color-group { margin-bottom: 40px; }
  .color-group-title {
    font-size: 20px;
    font-weight: 500;
    line-height: 1.2;
    margin-bottom: 20px;
    color: var(--ghost-white);
  }
  .color-grid {
    display: grid;
    grid-template-columns: repeat(auto-fill, minmax(180px, 1fr));
    gap: 16px;
  }
  .color-swatch {
    border: 1px solid var(--border-mist-10);
    border-radius: 4px;
    overflow: hidden;
  }
  .color-swatch-block {
    height: 80px;
    position: relative;
  }
  .color-swatch-info {
    padding: 12px;
    background: var(--color-black);
  }
  .color-swatch-name { font-size: 13px; font-weight: 500; margin-bottom: 2px; }
  .color-swatch-hex { font-family: var(--font-mono); font-size: 12px; color: var(--ghost-white); margin-bottom: 4px; }
  .color-swatch-role { font-size: 12px; color: var(--muted-smoke); line-height: 1.4; }

  /* TYPOGRAPHY */
  .type-sample { margin-bottom: 32px; padding-bottom: 32px; border-bottom: 1px solid var(--border-mist-04); }
  .type-sample:last-child { border-bottom: none; }
  .type-sample-text { margin-bottom: 8px; }
  .type-sample-label {
    font-family: var(--font-mono);
    font-size: 12px;
    color: var(--muted-smoke);
    letter-spacing: -0.24px;
  }

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

  /* CARDS */
  .card-grid { display: grid; grid-template-columns: repeat(auto-fit, minmax(300px, 1fr)); gap: 24px; }
  .card {
    background: var(--color-black);
    border-radius: 4px;
    padding: 28px;
  }
  .card-standard { border: 1px solid var(--border-mist-10); }
  .card-brutalist {
    border: 1px solid var(--border-mist-10);
    box-shadow: 4px 4px 0px 0px rgba(0,0,0,0.15);
  }
  .card-glow {
    border: 1px solid var(--border-mist-10);
    box-shadow: 0px 8px 32px rgba(0,0,0,0.5);
    position: relative;
  }
  .card-glow::before {
    content: '';
    position: absolute;
    inset: -1px;
    border-radius: 4px;
    background: radial-gradient(ellipse at center, rgba(0,255,255,0.06) 0%, transparent 70%);
    pointer-events: none;
    z-index: 0;
  }
  .card h3 { font-size: 24px; font-weight: 500; line-height: 1.2; margin-bottom: 12px; position: relative; z-index: 1; }
  .card p { color: var(--ghost-white); font-size: 15px; line-height: 1.63; position: relative; z-index: 1; }
  .card-label {
    font-family: var(--font-mono);
    font-size: 11px;
    text-transform: uppercase;
    letter-spacing: 0.55px;
    color: var(--color-cyan);
    margin-bottom: 16px;
    position: relative;
    z-index: 1;
  }

  /* FORMS */
  .form-grid { display: grid; grid-template-columns: 1fr 1fr; gap: 24px; }
  .form-group { margin-bottom: 20px; }
  .form-label {
    display: block;
    font-size: 13px;
    font-weight: 500;
    margin-bottom: 8px;
    color: var(--ghost-white);
  }
  .form-input {
    width: 100%;
    padding: 10px 14px;
    background: transparent;
    border: 1px solid var(--border-mist-10);
    border-radius: 4px;
    color: var(--color-white);
    font-size: 16px;
    font-family: var(--font-sans);
    outline: none;
    transition: border-color 0.2s;
  }
  .form-input::placeholder { color: var(--whisper-white); }
  .form-input-focus { border-color: var(--color-signal-blue); }
  .form-input-error { border-color: #ff4444; }
  .form-error-text { font-size: 12px; color: #ff4444; margin-top: 6px; }
  textarea.form-input { min-height: 100px; resize: vertical; }

  /* SPACING */
  .spacing-row { display: flex; flex-wrap: wrap; gap: 12px; align-items: flex-end; }
  .spacing-item { text-align: center; }
  .spacing-box {
    background: var(--cyan-12);
    border: 1px solid rgba(0,255,255,0.3);
    border-radius: 2px;
    margin-bottom: 8px;
  }
  .spacing-label {
    font-family: var(--font-mono);
    font-size: 11px;
    color: var(--muted-smoke);
  }

  /* RADIUS */
  .radius-row { display: flex; flex-wrap: wrap; gap: 20px; align-items: center; }
  .radius-item { text-align: center; }
  .radius-box {
    width: 80px;
    height: 80px;
    background: var(--color-black);
    border: 1px solid var(--border-mist-12);
    margin-bottom: 8px;
  }
  .radius-label {
    font-family: var(--font-mono);
    font-size: 11px;
    color: var(--muted-smoke);
  }
  .radius-context {
    font-size: 11px;
    color: var(--muted-smoke);
    margin-top: 2px;
  }

  /* ELEVATION */
  .elevation-grid { display: grid; grid-template-columns: repeat(auto-fit, minmax(220px, 1fr)); gap: 24px; }
  .elevation-card {
    background: var(--color-black);
    border-radius: 4px;
    padding: 24px;
    min-height: 140px;
    display: flex;
    flex-direction: column;
    justify-content: space-between;
  }
  .elevation-flat { border: none; }
  .elevation-contained { border: 1px solid var(--border-mist-06); }
  .elevation-standard { border: 1px solid var(--border-mist-10); }
  .elevation-brutalist {
    border: 1px solid var(--border-mist-10);
    box-shadow: 4px 4px 0px 0px rgba(0,0,0,0.15);
  }
  .elevation-floating {
    border: 1px solid var(--border-mist-10);
    box-shadow: 0px 8px 32px rgba(0,0,0,0.5);
  }
  .elevation-name { font-size: 16px; font-weight: 500; margin-bottom: 8px; }
  .elevation-desc { font-size: 13px; color: var(--ghost-white); line-height: 1.5; }
  .elevation-level {
    font-family: var(--font-mono);
    font-size: 11px;
    color: var(--color-cyan);
    text-transform: uppercase;
    letter-spacing: 0.55px;
    margin-top: 12px;
  }

  /* RESPONSIVE */
  @media (max-width: 768px) {
    .nav { padding: 12px 20px; }
    .nav-links a:not(.nav-cta-wrapper) { display: none; }
    .hero { padding: 80px 20px 60px; }
    .hero h1 { font-size: 36px; }
    .section { padding: 60px 20px; }
    .section-heading { font-size: 28px; }
    .color-grid { grid-template-columns: repeat(auto-fill, minmax(140px, 1fr)); }
    .form-grid { grid-template-columns: 1fr; }
    .card-grid { grid-template-columns: 1fr; }
    .hero-buttons { flex-direction: column; align-items: center; }
    .button-row { flex-direction: column; align-items: flex-start; }
  }
</style>
</head>
<body>

<!-- NAV -->
<nav class="nav">
  <div class="nav-brand">Composio</div>
  <div class="nav-links">
    <a href="#colors">Colors</a>
    <a href="#typography">Typography</a>
    <a href="#buttons">Buttons</a>
    <a href="#cards">Cards</a>
    <a href="#forms">Forms</a>
    <a href="#spacing">Spacing</a>
    <a href="#elevation">Elevation</a>
    <button class="nav-cta">Get Started</button>
  </div>
</nav>

<!-- HERO -->
<section class="hero">
  <h1>Design System Preview:<br>Composio</h1>
  <p>Auto-generated design token catalog from DESIGN.md</p>
  <div class="hero-buttons">
    <button class="btn-primary">Explore Tokens</button>
    <button class="btn-cyan">View Source</button>
  </div>
</section>

<hr class="section-divider">

<!-- COLORS -->
<section class="section" id="colors">
  <div class="section-title">01 / Color Palette</div>
  <h2 class="section-heading">Color Palette & Roles</h2>

  <div class="color-group">
    <h3 class="color-group-title">Primary</h3>
    <div class="color-grid">
      <div class="color-swatch">
        
        <div class="color-swatch-info">
          <div class="color-swatch-name">Composio Cobalt</div>
          <div class="color-swatch-hex">#0007cd</div>
          <div class="color-swatch-role">Core brand color for high-priority interactive elements</div>
        </div>
      </div>
    </div>
  </div>

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

  <div class="color-group">
    <h3 class="color-group-title">Surface & Background</h3>
    <div class="color-grid">
      <div class="color-swatch">
        
        <div class="color-swatch-info">
          <div class="color-swatch-name">Void Black</div>
          <div class="color-swatch-hex">#0f0f0f</div>
          <div class="color-swatch-role">Primary page background</div>
        </div>
      </div>
      <div class="color-swatch">
        
        <div class="color-swatch-info">
          <div class="color-swatch-name">Pure Black</div>
          <div class="color-swatch-hex">#000000</div>
          <div class="color-swatch-role">Card interiors and deep-nested containers</div>
        </div>
      </div>
      <div class="color-swatch">
        
        <div class="color-swatch-info">
          <div class="color-swatch-name">Charcoal</div>
          <div class="color-swatch-hex">#2c2c2c</div>
          <div class="color-swatch-role">Secondary button borders and dividers</div>
        </div>
      </div>
    </div>
  </div>

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

  <div class="color-group">
    <h3 class="color-group-title">Border System</h3>
    <div class="color-grid">
      <div class="color-swatch">
        <div class="color-swatch-block" style="background: var(--color-void); display: flex; align-items: center; justify-content: center;"></div>
        <div class="color-swatch-info">
          <div class="color-swatch-name">Border Mist 12</div>
          <div class="color-swatch-hex">rgba(255,255,255,0.12)</div>
          <div class="color-swatch-role">Prominent card edges, content separators</div>
        </div>
      </div>
      <div class="color-swatch">
        <div class="color-swatch-block" style="background: var(--color-void); display: flex; align-items: center; justify-content: center;"></div>
        <div class="color-swatch-info">
          <div class="color-swatch-name">Border Mist 10</div>
          <div class="color-swatch-hex">rgba(255,255,255,0.10)</div>
          <div class="color-swatch-role">Standard container borders</div>
        </div>
      </div>
      <div class="color-swatch">
        <div class="color-swatch-block" style="background: var(--color-void); display: flex; align-items: center; justify-content: center;"></div>
        <div class="color-swatch-info">
          <div class="color-swatch-name">Border Mist 06</div>
          <div class="color-swatch-hex">rgba(255,255,255,0.06)</div>
          <div class="color-swatch-role">Section dividers, subtle groupings</div>
        </div>
      </div>
      <div class="color-swatch">
        <div class="color-swatch-block" style="background: var(--color-void); display: flex; align-items: center; justify-content: center;"></div>
        <div class="color-swatch-info">
          <div class="color-swatch-name">Border Mist 04</div>
          <div class="color-swatch-hex">rgba(255,255,255,0.04)</div>
          <div class="color-swatch-role">Faintest atmospheric separation</div>
        </div>
      </div>
    </div>
  </div>
</section>

<hr class="section-divider">

<!-- TYPOGRAPHY -->
<section class="section" id="typography">
  <div class="section-title">02 / Typography Scale</div>
  <h2 class="section-heading">Typography Rules</h2>

  <div class="type-sample">
    <div class="type-sample-text" style="font-size: 64px; font-weight: 400; line-height: 0.87;">Display Hero</div>
    <div class="type-sample-label">Display / Hero &mdash; 64px / 400 / 0.87 / normal &mdash; abcDiatype</div>
  </div>

  <div class="type-sample">
    <div class="type-sample-text" style="font-size: 48px; font-weight: 400; line-height: 1.0;">Section Heading</div>
    <div class="type-sample-label">Section Heading &mdash; 48px / 400 / 1.00 / normal &mdash; abcDiatype</div>
  </div>

  <div class="type-sample">
    <div class="type-sample-text" style="font-size: 40px; font-weight: 400; line-height: 1.0;">Sub-heading Large</div>
    <div class="type-sample-label">Sub-heading Large &mdash; 40px / 400 / 1.00 / normal &mdash; abcDiatype</div>
  </div>

  <div class="type-sample">
    <div class="type-sample-text" style="font-size: 28px; font-weight: 400; line-height: 1.2;">Sub-heading</div>
    <div class="type-sample-label">Sub-heading &mdash; 28px / 400 / 1.20 / normal &mdash; abcDiatype</div>
  </div>

  <div class="type-sample">
    <div class="type-sample-text" style="font-size: 24px; font-weight: 500; line-height: 1.2;">Card Title</div>
    <div class="type-sample-label">Card Title &mdash; 24px / 500 / 1.20 / normal &mdash; abcDiatype</div>
  </div>

  <div class="type-sample">
    <div class="type-sample-text" style="font-size: 20px; font-weight: 500; line-height: 1.2;">Feature Label</div>
    <div class="type-sample-label">Feature Label &mdash; 20px / 500 / 1.20 / normal &mdash; abcDiatype</div>
  </div>

  <div class="type-sample">
    <div class="type-sample-text" style="font-size: 18px; font-weight: 400; line-height: 1.2;">Body Large</div>
    <div class="type-sample-label">Body Large &mdash; 18px / 400 / 1.20 / normal &mdash; abcDiatype</div>
  </div>

  <div class="type-sample">
    <div class="type-sample-text" style="font-size: 16px; font-weight: 400; line-height: 1.5;">Body / Button Text</div>
    <div class="type-sample-label">Body / Button &mdash; 16px / 400 / 1.50 / normal &mdash; abcDiatype</div>
  </div>

  <div class="type-sample">
    <div class="type-sample-text" style="font-size: 15px; font-weight: 400; line-height: 1.63;">Body Small &mdash; used for longer-form content blocks</div>
    <div class="type-sample-label">Body Small &mdash; 15px / 400 / 1.63 / normal &mdash; abcDiatype</div>
  </div>

  <div class="type-sample">
    <div class="type-sample-text" style="font-size: 14px; font-weight: 400; line-height: 1.63; color: var(--ghost-white);">Caption text for descriptions and metadata</div>
    <div class="type-sample-label">Caption &mdash; 14px / 400 / 1.63 / normal &mdash; abcDiatype</div>
  </div>

  <div class="type-sample">
    <div class="type-sample-text" style="font-size: 13px; font-weight: 500; line-height: 1.5;">Label Text</div>
    <div class="type-sample-label">Label &mdash; 13px / 500 / 1.50 / normal &mdash; abcDiatype</div>
  </div>

  <div class="type-sample">
    <div class="type-sample-text" style="font-size: 12px; font-weight: 500; line-height: 1.0; text-transform: uppercase; letter-spacing: 0.3px;">TAG / OVERLINE</div>
    <div class="type-sample-label">Tag / Overline &mdash; 12px / 500 / 1.00 / 0.3px / uppercase &mdash; abcDiatype</div>
  </div>

  <div class="type-sample">
    <div class="type-sample-text" style="font-family: var(--font-mono); font-size: 16px; font-weight: 400; line-height: 1.5; letter-spacing: -0.32px;">const agent = composio.create({ tools: ["github", "slack"] })</div>
    <div class="type-sample-label">Code Body &mdash; 16px / 400 / 1.50 / -0.32px &mdash; JetBrains Mono</div>
  </div>

  <div class="type-sample">
    <div class="type-sample-text" style="font-family: var(--font-mono); font-size: 14px; font-weight: 400; line-height: 1.5; letter-spacing: -0.28px;">npx composio-cli init --framework langchain</div>
    <div class="type-sample-label">Code Small &mdash; 14px / 400 / 1.50 / -0.28px &mdash; JetBrains Mono</div>
  </div>

  <div class="type-sample">
    <div class="type-sample-text" style="font-family: var(--font-mono); font-size: 12px; font-weight: 400; line-height: 1.5; letter-spacing: -0.28px;">import { Composio } from "composio-core"</div>
    <div class="type-sample-label">Code Caption &mdash; 12px / 400 / 1.50 / -0.28px &mdash; JetBrains Mono</div>
  </div>

  <div class="type-sample">
    <div class="type-sample-text" style="font-family: var(--font-mono); font-size: 14px; font-weight: 400; line-height: 1.43; text-transform: uppercase; letter-spacing: 0.7px;">CODE OVERLINE</div>
    <div class="type-sample-label">Code Overline &mdash; 14px / 400 / 1.43 / 0.7px / uppercase &mdash; JetBrains Mono</div>
  </div>

  <div class="type-sample">
    <div class="type-sample-text" style="font-family: var(--font-mono); font-size: 11px; font-weight: 400; line-height: 1.33; text-transform: uppercase; letter-spacing: 0.55px;">CODE MICRO TAG</div>
    <div class="type-sample-label">Code Micro &mdash; 11px / 400 / 1.33 / 0.55px / uppercase &mdash; JetBrains Mono</div>
  </div>
</section>

<hr class="section-divider">

<!-- BUTTONS -->
<section class="section" id="buttons">
  <div class="section-title">03 / Button Variants</div>
  <h2 class="section-heading">Buttons</h2>

  <div class="button-row">
    <div class="button-demo">
      <button class="btn-primary">Get Started</button>
      <div class="button-demo-label">Primary / White Fill</div>
    </div>
    <div class="button-demo">
      <button class="btn-cyan">View Docs</button>
      <div class="button-demo-label">Cyan Accent CTA</div>
    </div>
    <div class="button-demo">
      <button class="btn-ghost-blue">Learn More</button>
      <div class="button-demo-label">Ghost / Signal Blue</div>
    </div>
    <div class="button-demo">
      <button class="btn-ghost-charcoal">Secondary</button>
      <div class="button-demo-label">Ghost / Charcoal</div>
    </div>
    <div class="button-demo">
      <button class="btn-phantom">Dismiss</button>
      <div class="button-demo-label">Phantom</div>
    </div>
  </div>
</section>

<hr class="section-divider">

<!-- CARDS -->
<section class="section" id="cards">
  <div class="section-title">04 / Card Examples</div>
  <h2 class="section-heading">Cards & Containers</h2>

  <div class="card-grid">
    <div class="card card-standard">
      <div class="card-label">Standard Card</div>
      <h3>Border Mist 10</h3>
      <p>Standard content card with subtle white border at 10% opacity and 4px radius. The default container for most content blocks.</p>
    </div>
    <div class="card card-brutalist">
      <div class="card-label">Brutalist Shadow</div>
      <h3>Hard Offset 4px</h3>
      <p>Distinctive hard-offset shadow (4px right, 4px down) at 15% opacity. Adds a raw, retro-computing personality to select elements.</p>
    </div>
    <div class="card card-glow">
      <div class="card-label">Floating + Glow</div>
      <h3>Cyan Glow Halo</h3>
      <p>Soft diffuse shadow (8px 32px) with a radial cyan gradient halo. Used for highest-emphasis elevated content and feature highlights.</p>
    </div>
  </div>
</section>

<hr class="section-divider">

<!-- FORMS -->
<section class="section" id="forms">
  <div class="section-title">05 / Form Elements</div>
  <h2 class="section-heading">Inputs & Forms</h2>

  <div class="form-grid">
    <div>
      <div class="form-group">
        <label class="form-label">Default Input</label>
        <input type="text" class="form-input" placeholder="Enter your API key...">
      </div>
      <div class="form-group">
        <label class="form-label">Focus State</label>
        <input type="text" class="form-input form-input-focus" value="composio-api-key-xxxxx">
      </div>
      <div class="form-group">
        <label class="form-label">Error State</label>
        <input type="text" class="form-input form-input-error" value="invalid-key">
        <div class="form-error-text">Invalid API key format</div>
      </div>
    </div>
    <div>
      <div class="form-group">
        <label class="form-label">Textarea</label>
        <textarea class="form-input" placeholder="Describe your agent's task..."></textarea>
      </div>
    </div>
  </div>
</section>

<hr class="section-divider">

<!-- SPACING -->
<section class="section" id="spacing">
  <div class="section-title">06 / Spacing Scale</div>
  <h2 class="section-heading">Spacing System</h2>
  <p style="color: var(--ghost-white); margin-bottom: 32px;">Base unit: 8px. Scale builds from 1px to 40px.</p>

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

<hr class="section-divider">

<!-- BORDER RADIUS -->
<section class="section">
  <div class="section-title">07 / Border Radius Scale</div>
  <h2 class="section-heading">Border Radius</h2>

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

<hr class="section-divider">

<!-- ELEVATION -->
<section class="section" id="elevation">
  <div class="section-title">08 / Elevation & Depth</div>
  <h2 class="section-heading">Depth & Elevation</h2>

  <div class="elevation-grid">
    <div class="elevation-card elevation-flat">
      <div>
        <div class="elevation-name">Flat</div>
        <div class="elevation-desc">No shadow, no border. Page background and inline text.</div>
      </div>
      <div class="elevation-level">Level 0</div>
    </div>
    <div class="elevation-card elevation-contained">
      <div>
        <div class="elevation-name">Contained</div>
        <div class="elevation-desc">Border Mist 04-08. Background groupings, subtle sections.</div>
      </div>
      <div class="elevation-level">Level 1</div>
    </div>
    <div class="elevation-card elevation-standard">
      <div>
        <div class="elevation-name">Card</div>
        <div class="elevation-desc">Border Mist 10-12. Standard content cards, code blocks.</div>
      </div>
      <div class="elevation-level">Level 2</div>
    </div>
    <div class="elevation-card elevation-brutalist">
      <div>
        <div class="elevation-name">Brutalist</div>
        <div class="elevation-desc">Hard offset shadow (4px 4px, 15% black). Distinctive feature highlights.</div>
      </div>
      <div class="elevation-level">Level 3</div>
    </div>
    <div class="elevation-card elevation-floating">
      <div>
        <div class="elevation-name">Floating</div>
        <div class="elevation-desc">Soft diffuse shadow (0px 8px 32px, 50% black). Modals, overlays.</div>
      </div>
      <div class="elevation-level">Level 4</div>
    </div>
  </div>
</section>

</body>
</html>

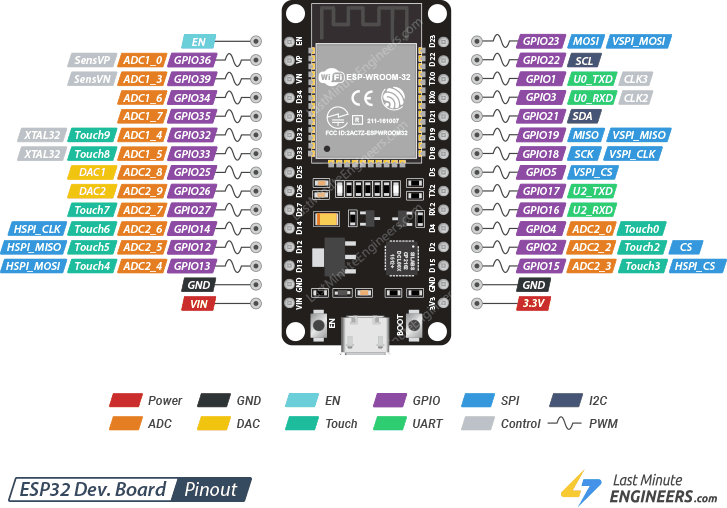
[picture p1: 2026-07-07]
firmware-python/pinout.png

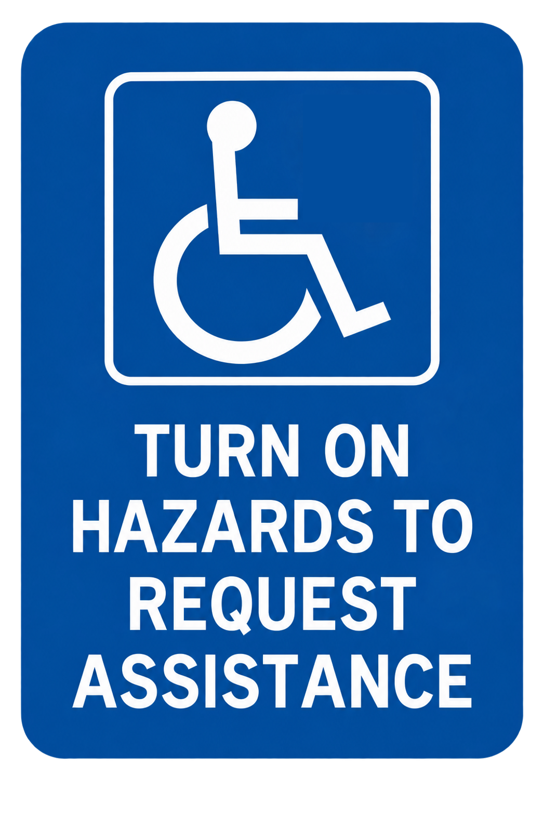
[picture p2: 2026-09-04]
HH.png

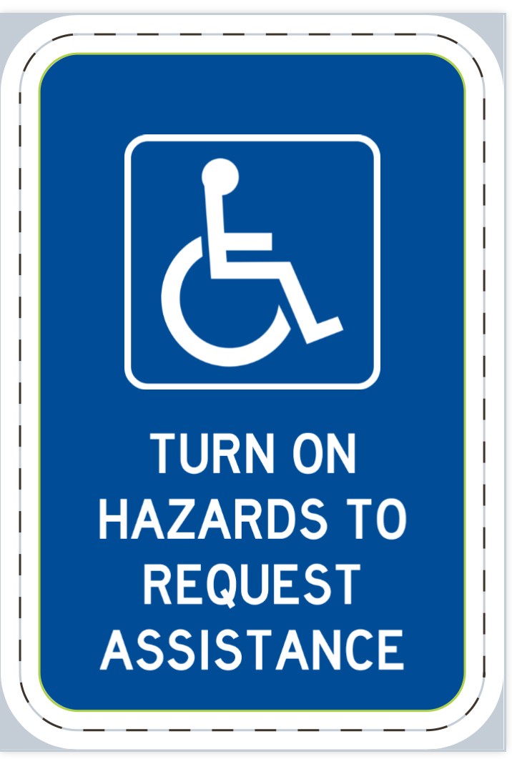
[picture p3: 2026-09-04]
HH_OG.jpg

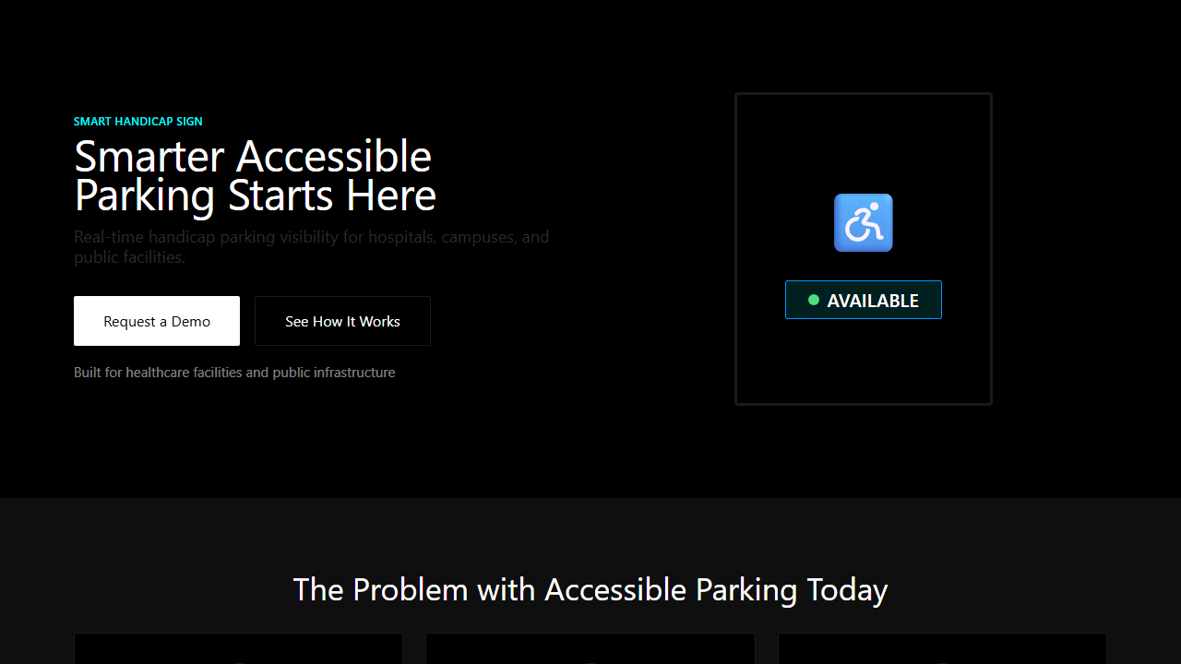
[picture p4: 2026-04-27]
frontend/apps/mobile/e2e/screenshots/landing-dark.png

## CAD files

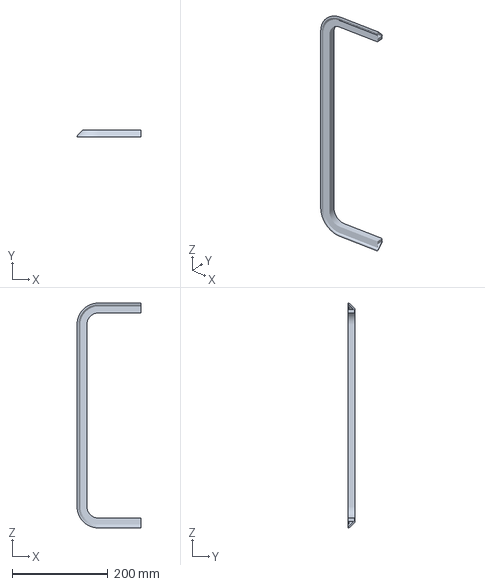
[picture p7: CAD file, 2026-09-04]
Unnamed-Straight.3mf
134.0 x 15.0 x 471.2 mm

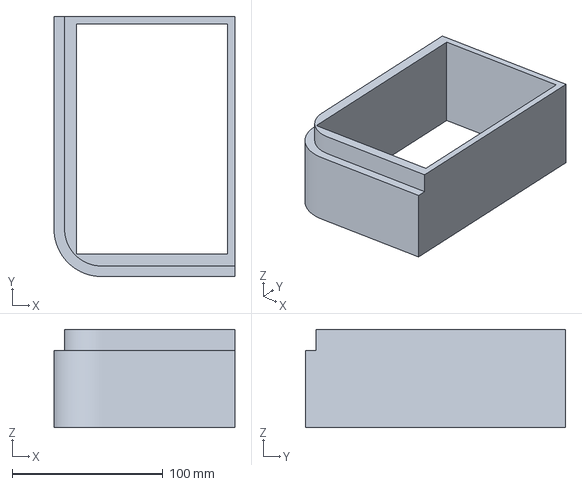
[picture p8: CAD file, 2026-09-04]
Unnamed-Battery Holder.3mf
119.9 x 172.3 x 65.1 mm

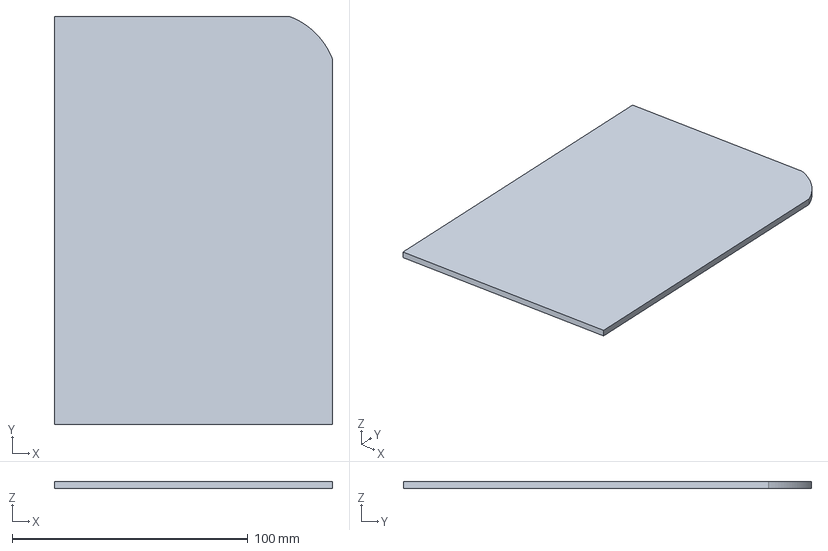
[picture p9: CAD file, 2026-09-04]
HazardHero-Enclosure Cover Left.3mf
118.2 x 173.2 x 3.00 mm

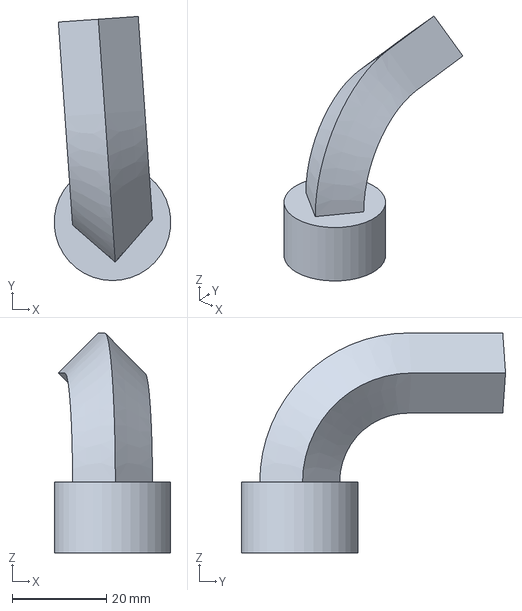
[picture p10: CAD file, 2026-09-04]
HazardHero-Photoresistor Mount.3mf
24.6 x 56.0 x 46.6 mm

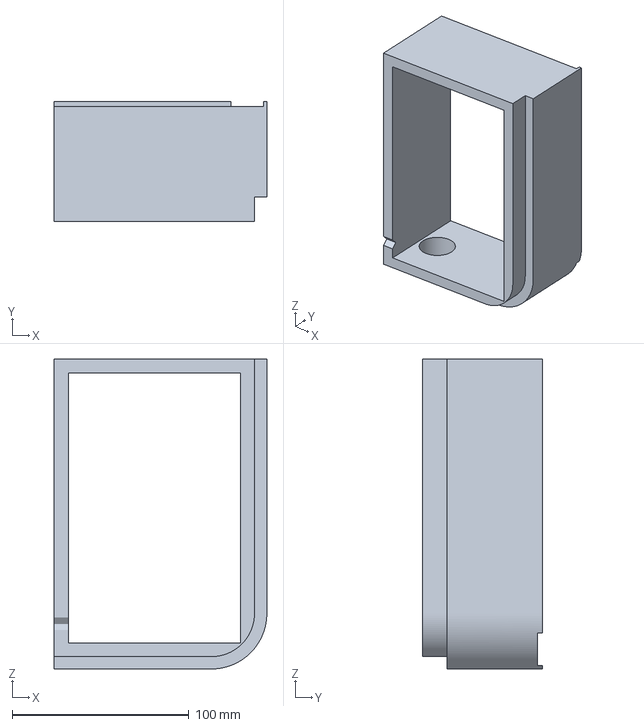
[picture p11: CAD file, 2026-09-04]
HazardHero-Enclosure Left.3mf
120.2 x 68.1 x 175.2 mm

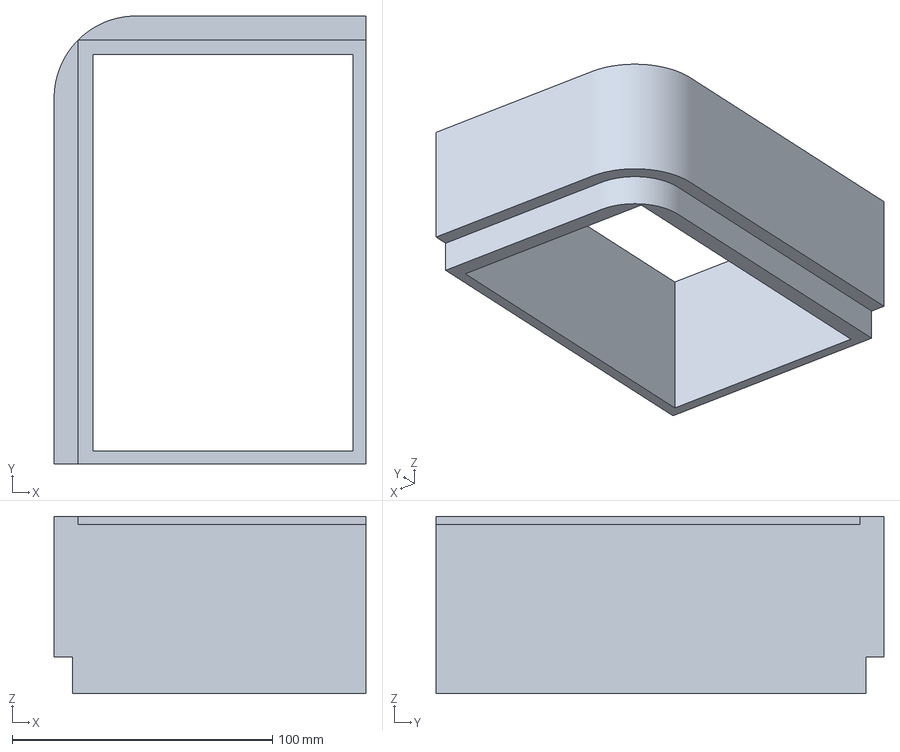
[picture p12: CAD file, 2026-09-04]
Unnamed-Enclosure.3mf
119.9 x 172.3 x 68.1 mm

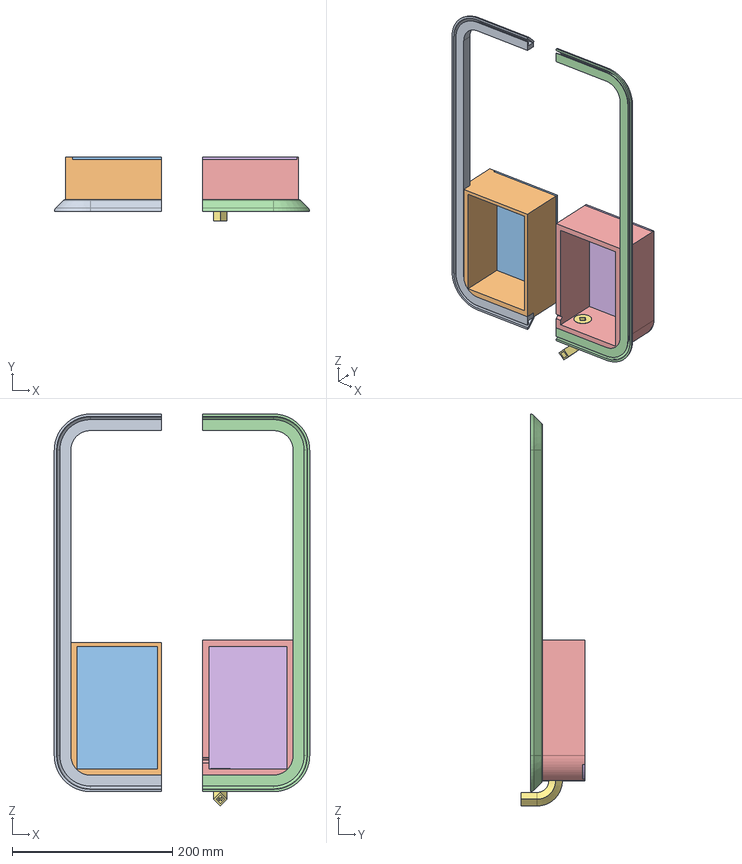
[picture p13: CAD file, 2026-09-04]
HazardHero.FCStd
318.8 x 79.7 x 489.0 mm
LED Mount Right
Enclosure Right
Enclousre Cover Right
LED Mount Left
Enclosure Left
Enclosure Cover Left
Photoresistor Mount

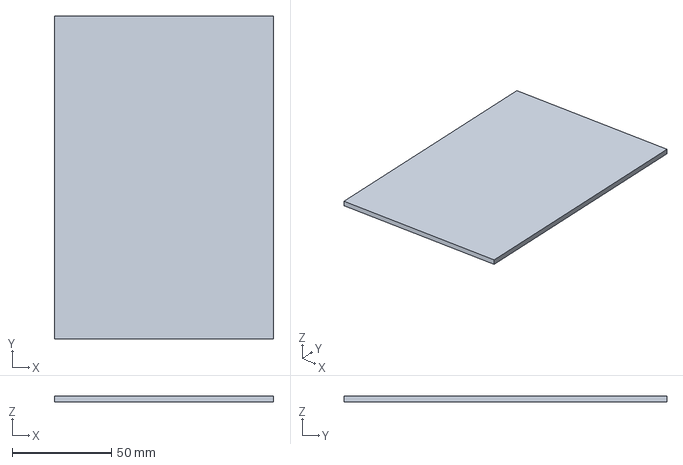
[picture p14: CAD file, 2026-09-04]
Unnamed-Enclousre CoverPad003.3mf
110.7 x 163.1 x 3.00 mm

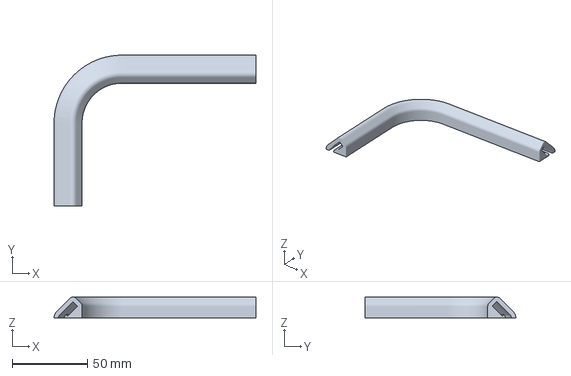
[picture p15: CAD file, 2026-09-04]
Unnamed-Body.3mf
134.0 x 100.0 x 13.8 mm

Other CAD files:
Unnamed-LED Mount Left.3mf
Unnamed-LED Mount.3mf
HH.blend
HazardHero.obj
pitch_iphone.blend

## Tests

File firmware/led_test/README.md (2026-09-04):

## WS2812B LED test

The test firmware drives a WS2812B strip from an ESP32 using the ESP-IDF
`led_strip` RMT backend.

At runtime, it turns the strip solid green for 5 seconds, turns it off for
5 seconds, and repeats. Change the `LED_TEST_STEP_INTERVAL_MS` definition in
`main/main.c` to adjust either interval.

Default configuration:

- `DATA_PIN`: GPIO4
- `NUM_LEDS`: 8
- `BRIGHTNESS`: 128
- Color order: GRB

Connect the buck converter's regulated 5 V and GND to the strip, connect the
ESP32 GND to the same ground, and route GPIO4 through a 330-470 ohm resistor
to the strip's `DIN`. A 1000 uF capacitor across the strip supply is
recommended. Configure the strip for 5.0 V before connecting it.

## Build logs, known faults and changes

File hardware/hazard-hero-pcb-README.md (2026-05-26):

# Hazard Hero PCB

This document describes the controller PCB exported as `hazard-hero-easyeda-pcb.json`.

> **Solar assumption for this revision:** assume a **10 W solar panel** is used in the field,
> but only **through a low-cost external non-MPPT solar charge controller and battery
> subsystem**. This PCB does **not** accept a panel directly and does **not** integrate charge
> control, battery protection, or power-path management.

At a high level, this board is the electrical backbone for a connected accessible parking sign node. It accepts field power, protects and regulates it, hosts the main controller module, provides an interface for an external modem/GNSS daughtercard, switches a sign or lamp load, reads external sensors, and exposes service connections for setup and maintenance.

## What the PCB does as a whole

In normal use, the board is intended to:

1. Accept a nominal 12 V input from the field wiring or from an external solar battery/charge-controller output.
2. Protect that input against overcurrent and transient spikes.
3. Convert the input rail into 5 V and then 3.3 V for logic electronics.
4. Host the main controller module that coordinates sensing, communications, and output control.
5. Provide a header for an external modem/GNSS module when wide-area connectivity is needed.
6. Drive a sign, lamp, or other field output through a MOSFET-based low-side switch.
7. Bring in external sensor signals and expose a UART/service header for setup and debug.

## System-level signal and power flow

The intended flow through the board is:

`12V input -> fuse/current limit -> TVS surge clamp -> 5V buck stage -> 3.3V LDO -> controller and low-voltage I/O`

The sign output path is:

`VIN_FUSED -> external sign/lamp load -> LAMP_RET -> Q1 low-side MOSFET -> GND`

That means the load connected to the sign output is powered from the fused supply and switched on the return side by the MOSFET.

## Major functional blocks

### 1. Power entry and protection

This section receives the incoming 12 V supply and makes it safe for the rest of the board.
For a solar-backed deployment, that 12 V rail is assumed to come from an **external 10 W solar
power subsystem**, not from the panel directly.

- **J1** is the main 12 V field power input. In a solar deployment it should be fed by the
  regulated output of a low-cost external PWM or fixed-voltage solar charge controller /
  battery pack sized around a 10 W panel.
- **F1** is the first protection element in series with VIN and is intended to act as a resettable fuse or current-limit placeholder.
- **D1** is a TVS diode that clamps spikes, surges, and other fast transients on the input rail.
- **U1** is a header/footprint area for an external buck regulator module that converts the protected input into 5 V.
- **U2** is a 3.3 V linear regulator that creates the main logic rail from 5 V.
- **D2 + R3** create a simple power-good indicator LED on the low-voltage rail.

### 2. Compute and control

This section is the local controller core.

- **U3** is the ESP32-S3 module area. It is the main controller footprint and breakout region.
- The controller is responsible for reading sensor inputs, managing output control, handling local service access, and interfacing with the modem header.
- An **antenna keep-out** region is marked so nearby copper, metal, or enclosure features do not interfere with the radio section of the module.

### 3. Communications expansion

This section allows the controller board to work with an external communications module.

- **U4** is a 2x10 header intended for a modem/GNSS daughtercard.
- The routed core signals include power and UART.
- Additional pads are present for modem control, USB, SIM, antenna, wake/status, and future expansion signals.

This makes the PCB a baseboard/controller board rather than a fully self-contained radio board.

### 4. High-current output stage

This section drives the sign or lamp load.

- **Q1** is a DPAK MOSFET used as the low-side switch.
- **R2** is a 100 ohm gate resistor between the controller output and the MOSFET gate.
- **J3** exposes the field-side sign interface, including fused supply, switched return, sensor input, and ground.

The low-side topology is simple and practical for switching loads, but the connected field device must be wired with that arrangement in mind.

### 5. Sensor and service access

This section provides low-voltage access for external peripherals and technicians.

- **J4** is the sensor header.
- **J5** is the UART/service header for setup, programming, recovery, or maintenance access.
- **J2** is a reserved auxiliary/battery header. In the current layout it is more of a provision
  point than a complete battery-management subsystem, and it is not a direct solar-panel input.

### 6. Mechanical support

- **H1-H4** are M3 mounting holes used to secure the PCB inside the sign enclosure or carrier.

## Component-by-component guide

| Ref | Block / package | What it does |
|---|---|---|
| **J1** | 2-pin terminal, `12V IN` | Main field power input for the board. For a solar-backed install, feed this from the regulated 12 V output of an external low-cost non-MPPT charge controller / battery subsystem sized around a 10 W panel. |
| **F1** | Series protection element, `PTC` placeholder | Limits fault current on the incoming VIN rail before power reaches the rest of the board. |
| **D1** | TVS diode, `TVS` | Clamps surge and transient events on the input supply. |
| **U1** | Buck module header, `5V BUCK` | Footprint/header area for an external DC/DC converter that generates the 5 V rail. |
| **U2** | SOT-223 regulator, `3V3 LDO` | Generates the 3.3 V logic rail for the controller and low-voltage interfaces. |
| **J2** | 2-pin terminal, `VBAT` | Reserved auxiliary/battery connection point for future backup or ride-through support. It is not a direct panel input and does not have on-board charge management. |
| **U3** | ESP32-S3 module area | Main controller footprint and breakout region. Intended to run local control, sensing, and communications interfacing. |
| **U4** | 2x10 modem/GNSS header, `MODEM HDR` | Expansion header for an external modem/GNSS daughtercard. |
| **Q1** | DPAK MOSFET, `MOSFET` | Low-side switch for the sign or lamp load. |
| **R2** | 0603 resistor, `100R` | Gate resistor for Q1; helps tame switching edges and protects the controller pin. |
| **D2** | 0603 LED, `PWR` | Power indicator LED showing that the low-voltage rail is present. |
| **R3** | 0603 resistor, `1K` | Current-limiting resistor for the power LED. |
| **J3** | 4-pin terminal, `SIGN IO` | Main field I/O connector for the sign load and one sensor input. |
| **J4** | 1x4 header, `SENSOR` | Low-voltage sensor header for simple external sensing connections. |
| **J5** | 1x6 header, `UART` | Service/programming/debug header for direct board access. |
| **H1-H4** | M3 mounting holes | Mechanical attachment points for the PCB. |

## Connector and interface summary

### J1 - 12V IN

- **Pin 1:** VIN
- **Pin 2:** GND

Main board power enters here.

For a solar deployment, **do not connect a 10 W panel directly to J1**. J1 should only see the
regulated output of an external non-MPPT charge controller / battery subsystem.

### J2 - VBAT

- **Pin 1:** VBAT
- **Pin 2:** GND

Reserved auxiliary or backup power connection. The current layout does not yet include a full
charger or power-path management circuit around it, so **do not connect a solar panel directly
to J2**.

### J3 - SIGN IO

- **Pin 1:** `VIN_FUSED`
- **Pin 2:** `LAMP_RET`
- **Pin 3:** `SENSOR_IN`
- **Pin 4:** `GND`

This is the primary field connector. A typical load would connect between `VIN_FUSED` and `LAMP_RET`, with `LAMP_RET` being switched by Q1.

### J4 - SENSOR

- **Pin 1:** `3V3`
- **Pin 2:** `SENSOR_IN`
- **Pin 3:** `I2C_SCL`
- **Pin 4:** `GND`

This is a light sensor/peripheral header for simple external sensing or future accessory hardware.

### J5 - UART

- **Pin 1:** `3V3`
- **Pin 2:** `GND`
- **Pin 3:** `UART_TXD`
- **Pin 4:** `UART_RXD`
- **Pin 5:** `EN`
- **Pin 6:** `IO0`

This header is intended for service access, boot mode control, recovery, and direct serial interaction with the controller module.

### U4 - MODEM HDR

The daughtercard header exposes the board's communications expansion interface. In the current layout, the most important routed signals are:

- `5V`
- `GND`
- `MODEM_RX`
- `MODEM_TX`

Pads are also reserved for modem control and future functions such as:

- `PWRKEY`
- `NETSTAT`
- `SIM_IO`
- `SIM_CLK`
- `SIM_RST`
- `ANT`
- `ANT_GND`
- `USB_DP`
- `USB_DM`
- `WAKE`
- `STATUS`

## How the main components work together

When field power enters through **J1**, it first passes through **F1**, then sees surge
protection at **D1**. The protected rail feeds **U1**, which is expected to generate **5 V**.
That 5 V rail then feeds **U2**, which produces the **3.3 V** logic rail used by the controller
and low-voltage interfaces.

Under the **10 W solar-panel assumption**, the board still expects a regulated 12 V input at
**J1**. The panel, a low-cost external non-MPPT charge controller, battery pack, and
low-voltage disconnect all remain external to this PCB revision.

The controller module at **U3** uses that logic rail and interacts with external hardware through **J4**, **J5**, and **U4**. When the controller needs to switch a sign or lamp load, it drives **Q1** through **R2**. The load itself is connected through **J3**, where it sees fused supply on one side and MOSFET-switched return on the other.

The power LED made by **D2** and **R3** gives a quick visual confirmation that the low-voltage logic rail is alive.

## Manufacturing and design assumptions

This README reflects the current PCB concept as laid out in the EasyEDA JSON file. The silkscreen notes on the board assume:

- **2-layer FR-4**
- **1.6 mm board thickness**
- **1 oz copper**
- Nominal **12 V** field input
- External **5 V buck module**
- Local **3.3 V** regulation on-board

### Solar deployment assumption

For planning purposes, this board can be considered part of a solar-backed system built around:

- A nominal **10 W solar panel**
- An **external low-cost non-MPPT** solar charge controller (PWM or fixed-voltage charger)
- An **external** battery pack sized for the site autonomy target
- A regulated **12 V output** delivered to **J1**

This assumption favors **lower cost over maximum energy harvest**. For a modest 10 W panel,
discarding MPPT is reasonable if the project can tolerate lower charging efficiency in weak sun,
temperature swings, or suboptimal panel orientation.

This assumption does **not** mean the board is itself solar-ready. A true integrated solar
revision would still need an on-board charger, power-path management, battery protection, and
likely a more efficient 3.3 V conversion stage.

## Estimated cost

These numbers are rough order-of-magnitude estimates for the current board concept, not vendor quotes.

| Scope | Rough cost |
|---|---:|
| Bare 2-layer PCB | **$3-8** |
| Assembled controller PCB | **$25-40** |
| Add modem/GNSS daughtercard and antenna | **+$20-45** |
| Add external solar kit (10 W panel, non-MPPT charge controller, battery, harnessing) | **+$30-70** |
| Add enclosure, harnessing, and final assembly | **+$20-35** |
| Estimated finished field unit with external 10 W solar subsystem | **$105-210** |

### What the estimate assumes

- Low-volume prototype or pilot-build quantities, not mass production.
- The communications hardware remains on an external daughtercard rather than being integrated directly onto the main PCB.
- The 5 V conversion stage is still treated as a module/header item rather than a fully integrated custom power stage.
- The estimate is centered on the controller board and nearby integration hardware, not a complete certified product program.
- The solar line item assumes a modest **10 W** panel with a lower-cost **non-MPPT** external charger and keeps all charging/battery hardware external to this PCB.

## Important current limitations

This board is best understood as a solid hardware direction and board-level concept, not a fully signed-off production release. Before fabrication for field use, it should still go through:

1. Full schematic capture review against the PCB.
2. Final footprint and BOM lock.
3. Decoupling and regulator stability review.
4. DRC/ERC cleanup and manufacturability review.
5. Thermal, surge, ESD, and EMC validation.
6. Output-stage load-current review for the actual lamp/sign hardware.
7. RF review around the controller antenna region and any modem daughtercard used.
8. External solar power-chain validation if deploying with the assumed **10 W** panel, including non-MPPT charge controller selection, battery sizing, low-voltage disconnect, and enclosure thermal review.

## Related file

- `hazard-hero-easyeda-pcb.json` - EasyEDA-style PCB JSON for this board

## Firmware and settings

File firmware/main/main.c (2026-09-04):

#include <stdbool.h>
#include <string.h>

#include "freertos/FreeRTOS.h"
#include "freertos/task.h"
#include "esp_system.h"
#include "esp_timer.h"
#include "esp_wifi.h"
#include "driver/gpio.h"
#include "esp_err.h"
#include "esp_log.h"
#include "esp_task_wdt.h"

#include "adc_sampler.h"
#include "boot_support.h"
#include "cloud_settings.h"
#include "device_manager.h"
#include "connection_policy.h"
#include "identity_service.h"
#include "iot_hub_client.h"
#include "led_driver.h"
#include "nvs_storage.h"
#include "runtime_config.h"
#include "wifi_manager.h"
#include "wifi_recovery.h"

static const char *TAG = "main";

#define TELEMETRY_RING_CAPACITY 200U
#define TELEMETRY_PUBLISH_INTERVAL_MS 5000U
#define HEARTBEAT_PUBLISH_INTERVAL_MS 60000U

typedef struct {
    int samples[TELEMETRY_RING_CAPACITY];
    size_t head;
    size_t tail;
    size_t count;
    portMUX_TYPE lock;
} telemetry_ring_t;

static telemetry_ring_t s_telemetry_ring = {
    .head = 0U,
    .tail = 0U,
    .count = 0U,
    .lock = portMUX_INITIALIZER_UNLOCKED,
};

static int get_wifi_rssi_dbm(void)
{
    wifi_ap_record_t ap_info;
    if (esp_wifi_sta_get_ap_info(&ap_info) != ESP_OK) {
        return -127;
    }
    return (int)ap_info.rssi;
}

static void telemetry_ring_push(int sample)
{
    portENTER_CRITICAL(&s_telemetry_ring.lock);

    s_telemetry_ring.samples[s_telemetry_ring.head] = sample;
    s_telemetry_ring.head = (s_telemetry_ring.head + 1U) % TELEMETRY_RING_CAPACITY;

    if (s_telemetry_ring.count == TELEMETRY_RING_CAPACITY) {
        s_telemetry_ring.tail = (s_telemetry_ring.tail + 1U) % TELEMETRY_RING_CAPACITY;
    } else {
        s_telemetry_ring.count++;
    }

    portEXIT_CRITICAL(&s_telemetry_ring.lock);
}

static size_t telemetry_ring_snapshot(int *buffer, size_t buffer_len)
{
    if (buffer == NULL || buffer_len == 0U) {
        return 0U;
    }

    portENTER_CRITICAL(&s_telemetry_ring.lock);

    size_t to_copy = s_telemetry_ring.count < buffer_len ? s_telemetry_ring.count : buffer_len;
    for (size_t i = 0U; i < to_copy; ++i) {
        size_t index = (s_telemetry_ring.tail + i) % TELEMETRY_RING_CAPACITY;
        buffer[i] = s_telemetry_ring.samples[index];
    }

    portEXIT_CRITICAL(&s_telemetry_ring.lock);
    return to_copy;
}

static void telemetry_ring_advance(size_t consumed)
{
    portENTER_CRITICAL(&s_telemetry_ring.lock);

    if (consumed >= s_telemetry_ring.count) {
        s_telemetry_ring.tail = s_telemetry_ring.head;
        s_telemetry_ring.count = 0U;
    } else {
        s_telemetry_ring.tail = (s_telemetry_ring.tail + consumed) % TELEMETRY_RING_CAPACITY;
        s_telemetry_ring.count -= consumed;
    }

    portEXIT_CRITICAL(&s_telemetry_ring.lock);
}

static void telemetry_sampler_task(void *arg)
{
    (void)arg;

    while (true) {
        int sample = adc_sampler_read_raw();
        if (sample >= 0) {
            telemetry_ring_push(sample);
        }

        vTaskDelay(pdMS_TO_TICKS(SAMPLE_INTERVAL_MS));
    }
}

void app_main(void)
{
    char serial_number[NVS_SERIAL_NUMBER_MAX_LEN + 1] = {0};
    char wifi_ssid[NVS_WIFI_SSID_MAX_LEN + 1] = {0};
    char wifi_password[NVS_WIFI_PASSWORD_MAX_LEN + 1] = {0};
    iot_hub_client_settings_t iot_hub_settings = {0};
    iot_hub_state_t cloud_state = {0};
    int reconnect_failures = 0;
    int64_t boot_time_us = esp_timer_get_time();
    int64_t last_heartbeat_us = 0;
    int64_t wifi_connected_since_us = 0;

    ESP_LOGI(TAG, "Hazard Hero firmware starting");

    esp_err_t err = nvs_storage_init();
    if (err != ESP_OK) {
        boot_support_fatal_restart("Failed to initialize NVS storage", err);
    }

    // Reset wifi credentials if GPIO0 is pressed at boot
    if (gpio_get_level(GPIO_NUM_0) == 0) {
        ESP_LOGI(TAG, "GPIO0 pressed at boot, resetting WiFi credentials");
        nvs_wifi_clear();
    }

    err = led_driver_init();
    if (err != ESP_OK) {
        boot_support_fatal_restart("Failed to initialize LED driver", err);
    }
    led_driver_set_status(STATUS_BOOTING);

    err = identity_service_load_device_serial_number(serial_number, sizeof(serial_number));
    if (err != ESP_OK) {
        boot_support_fatal_restart("Failed to load device serial number", err);
    }
    ESP_LOGI(TAG, "Device serial number: %s", serial_number);

    err = wifi_manager_init();
    if (err != ESP_OK) {
        boot_support_fatal_restart("Failed to initialize WiFi manager", err);
    }

    if (!nvs_wifi_exists()) {
        boot_support_enter_provisioning_mode("No WiFi credentials found in NVS");
    }

    led_driver_set_status(STATUS_CONNECTING);
    err = nvs_wifi_load(wifi_ssid, sizeof(wifi_ssid), wifi_password, sizeof(wifi_password));
    if (err != ESP_OK) {
        boot_support_fatal_restart("Failed to load WiFi credentials", err);
    }

    err = wifi_sta_connect(wifi_ssid, wifi_password, WIFI_CONNECT_TIMEOUT_MS);
    memset(wifi_password, 0, sizeof(wifi_password));
    memset(wifi_ssid, 0, sizeof(wifi_ssid));
    if (err != ESP_OK) {
        ESP_LOGW(TAG, "Initial WiFi connection failed: %s", esp_err_to_name(err));
        led_driver_set_status(STATUS_ERROR);
        if (should_enter_provisioning_on_initial_connect_failure(nvs_wifi_is_validated())) {
            boot_support_enter_provisioning_mode("Unable to connect with saved WiFi credentials");
        }
        ESP_LOGW(TAG, "Saved WiFi credentials were previously validated; continuing without provisioning mode");
    } else {
        esp_err_t validated_err = nvs_wifi_set_validated(true);
        if (validated_err != ESP_OK) {
            ESP_LOGW(TAG, "Connected to WiFi but failed to persist validated flag: %s", esp_err_to_name(validated_err));
        }
        led_driver_set_status(STATUS_AVAILABLE);
        wifi_connected_since_us = esp_timer_get_time();
    }

    vTaskDelay(pdMS_TO_TICKS(NETWORK_STABILITY_DELAY_MS));

    err = adc_sampler_init();
    if (err != ESP_OK) {
        boot_support_fatal_restart("Failed to initialize ADC sampler", err);
    }

    err = battery_manager_init_adc();
    if (err != ESP_OK) {
        boot_support_fatal_restart("Failed to initialize battery manager ADC channel", err);
    }

    BaseType_t task_result = xTaskCreate(telemetry_sampler_task, "telemetry_sampler", 4096, NULL, 5, NULL);
    if (task_result != pdPASS) {
        boot_support_fatal_restart("Failed to start telemetry sampler task", ESP_FAIL);
    }

    err = cloud_settings_resolve_iot_hub_settings_x509(serial_number, &iot_hub_settings);
    if (err != ESP_OK) {
        boot_support_fatal_restart("Failed to build IoT Hub settings", err);
    }

    err = iot_hub_client_init(&iot_hub_settings, NULL);
    if (err != ESP_OK) {
        boot_support_fatal_restart("Failed to initialize IoT Hub client", err);
    }

    err = iot_hub_client_start();
    if (err != ESP_OK && err != ESP_ERR_NOT_FOUND) {
        ESP_LOGW(TAG, "IoT Hub client did not start cleanly: %s", esp_err_to_name(err));
    }

    err = iot_hub_client_get_state(&cloud_state);
    if (err != ESP_OK) {
        boot_support_fatal_restart("Failed to load cached IoT Hub state", err);
    }
    led_driver_set_status(cloud_state.operational_status);

    err = boot_support_init_task_wdt();
    if (err != ESP_OK) {
        boot_support_fatal_restart("Failed to initialize task watchdog", err);
    }

    ESP_LOGI(TAG, "Initialization complete; entering main loop");

    while (true) {
        ESP_LOGI(TAG, "Main loop iteration");
        esp_task_wdt_reset();

        err = iot_hub_client_get_state(&cloud_state);
        if (err != ESP_OK) {
            ESP_LOGE(TAG, "Failed to read cached IoT Hub state: %s", esp_err_to_name(err));
            led_driver_set_status(STATUS_ERROR);
            vTaskDelay(pdMS_TO_TICKS(TELEMETRY_PUBLISH_INTERVAL_MS));
            continue;
        }

        led_driver_set_status(cloud_state.operational_status);

        if (!wifi_sta_is_connected()) {
            led_driver_set_status(STATUS_CONNECTING);
            err = wifi_recovery_attempt(&reconnect_failures);
            if (err == ESP_OK) {
                wifi_connected_since_us = esp_timer_get_time();
                vTaskDelay(pdMS_TO_TICKS(NETWORK_STABILITY_DELAY_MS));
            } else {
                vTaskDelay(pdMS_TO_TICKS(TELEMETRY_PUBLISH_INTERVAL_MS));
            }
            continue;
        }

        if (wifi_connected_since_us == 0) {
            wifi_connected_since_us = esp_timer_get_time();
        }

        reconnect_failures = 0;

        int64_t now_us = esp_timer_get_time();
        if (last_heartbeat_us == 0 || (now_us - last_heartbeat_us) >= (int64_t)HEARTBEAT_PUBLISH_INTERVAL_MS * 1000LL) {
            iot_hub_state_t heartbeat_state = {0};
            err = iot_hub_client_get_state(&heartbeat_state);
            if (err == ESP_OK) {
                uint32_t uptime_ms = (uint32_t)((now_us - boot_time_us) / 1000LL);
                uint32_t wifi_connected_ms = (uint32_t)((now_us - wifi_connected_since_us) / 1000LL);
                int wifi_rssi_dbm = get_wifi_rssi_dbm();
                err = iot_hub_client_publish_heartbeat(
                    uptime_ms,
                    wifi_connected_ms,
                    wifi_rssi_dbm,
                    battery_manager_read_percentage(),
                    heartbeat_state.telemetry_interval_ms,
                    heartbeat_state.telemetry_enabled,
                    heartbeat_state.operational_status);
                if (err == ESP_OK) {
                    last_heartbeat_us = now_us;
                } else {
                    ESP_LOGW(TAG, "Heartbeat publish deferred: %s", esp_err_to_name(err));
                }
            } else {
                ESP_LOGW(TAG, "Heartbeat state unavailable: %s", esp_err_to_name(err));
            }
        }

        if (!cloud_state.telemetry_enabled) {
            vTaskDelay(pdMS_TO_TICKS(TELEMETRY_PUBLISH_INTERVAL_MS));
            continue;
        }

        if (cloud_state.operational_status != STATUS_AVAILABLE) {
            ESP_LOGI(TAG, "Skipping telemetry while status is %d", cloud_state.operational_status);
            vTaskDelay(pdMS_TO_TICKS(TELEMETRY_PUBLISH_INTERVAL_MS));
            continue;
        }

        int publish_buffer[TELEMETRY_RING_CAPACITY] = {0};
        size_t publish_count = telemetry_ring_snapshot(publish_buffer, TELEMETRY_RING_CAPACITY);

        if (publish_count > 0U) {
            // Don't publish telemetry if the range of the data is less than the minimum meaningful threshold
            int min_value = publish_buffer[0];
            int max_value = publish_buffer[0];
            for (size_t i = 1; i < publish_count; ++i) {
                if (publish_buffer[i] < min_value) {
                    min_value = publish_buffer[i];
                }
                if (publish_buffer[i] > max_value) {
                    max_value = publish_buffer[i];
                }
            }
            if ((max_value - min_value) < 217U) {
                ESP_LOGI(TAG, "Telemetry range too small, skipping publish");
                vTaskDelay(pdMS_TO_TICKS(TELEMETRY_PUBLISH_INTERVAL_MS / 4));
                continue;
            }

            err = iot_hub_client_publish_telemetry(publish_buffer, publish_count);
            if (err == ESP_OK) {
                telemetry_ring_advance(publish_count);
            } else {
                ESP_LOGW(TAG, "Telemetry publish deferred: %s", esp_err_to_name(err));
            }
        }

        vTaskDelay(pdMS_TO_TICKS(TELEMETRY_PUBLISH_INTERVAL_MS));
    }
}

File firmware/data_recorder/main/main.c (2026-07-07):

#include <stdbool.h>
#include <stdio.h>
#include <stdlib.h>
#include <string.h>

#include "cJSON.h"
#include "esp_err.h"
#include "esp_http_client.h"
#include "esp_log.h"
#include "freertos/FreeRTOS.h"
#include "freertos/task.h"
#include "nvs_flash.h"

#include "adc_sampler.h"
#include "wifi_manager.h"

#ifndef DEV_BACKEND_URL
#define DEV_BACKEND_URL "http://192.168.7.168:8000/api/v1/dev/training-captures"
#endif
#ifndef DEV_WIFI_SSID
#define DEV_WIFI_SSID "222 Potomac WiFi"
#endif
#ifndef DEV_WIFI_PASSWORD
#define DEV_WIFI_PASSWORD "Everhart12052026"
#endif
#ifndef DEV_DEVICE_SERIAL
#define DEV_DEVICE_SERIAL ""
#endif
#ifndef DEV_FIRMWARE_VERSION
#define DEV_FIRMWARE_VERSION "dev"
#endif

#define DEV_REQUEST_TIMEOUT_MS 5000

static const char *TAG = "data_recorder";
static int s_samples[SAMPLES_PER_BATCH];

static void post_capture(const int *samples, size_t sample_count)
{
    if (DEV_BACKEND_URL[0] == '\0') {
        return;
    }

    cJSON *root = cJSON_CreateObject();
    if (root == NULL) {
        return;
    }

    cJSON *sample_array = cJSON_CreateArray();
    if (sample_array == NULL) {
        cJSON_Delete(root);
        return;
    }

    for (size_t i = 0; i < sample_count; ++i) {
        cJSON_AddItemToArray(sample_array, cJSON_CreateNumber(samples[i]));
    }

    cJSON_AddStringToObject(root, "serial_number", DEV_DEVICE_SERIAL[0] != '\0' ? DEV_DEVICE_SERIAL : "dev-unknown");
    cJSON_AddStringToObject(root, "firmware_version", DEV_FIRMWARE_VERSION);
    cJSON_AddNumberToObject(root, "sample_count", (double)sample_count);
    cJSON_AddNumberToObject(root, "sample_interval_ms", SAMPLE_INTERVAL_MS);
    cJSON_AddItemToObject(root, "samples", sample_array);

    char *body = cJSON_PrintUnformatted(root);
    cJSON_Delete(root);
    if (body == NULL) {
        return;
    }

    const bool is_https = strncmp(DEV_BACKEND_URL, "https://", 8) == 0;
    ESP_LOGI(TAG, "Posting capture to %s", DEV_BACKEND_URL);

    esp_http_client_config_t config = {
        .url = DEV_BACKEND_URL,
        .timeout_ms = DEV_REQUEST_TIMEOUT_MS,
        .transport_type = is_https ? HTTP_TRANSPORT_OVER_SSL : HTTP_TRANSPORT_OVER_TCP,
    };

    esp_http_client_handle_t client = esp_http_client_init(&config);
    if (client != NULL) {
        esp_http_client_set_method(client, HTTP_METHOD_POST);
        esp_http_client_set_header(client, "Content-Type", "application/json");
        esp_http_client_set_post_field(client, body, (int)strlen(body));
        esp_err_t err = esp_http_client_perform(client);
        if (err != ESP_OK) {
            ESP_LOGE(TAG, "Capture upload failed: %s", esp_err_to_name(err));
        }
        esp_http_client_cleanup(client);
    }

    free(body);
}

void app_main(void)
{
    ESP_LOGI(TAG, "Data recorder starting");

    (void)nvs_flash_init();
    (void)adc_sampler_init();
    (void)wifi_manager_init();
    if (DEV_WIFI_SSID[0] != '\0') {
        (void)wifi_sta_connect(DEV_WIFI_SSID, DEV_WIFI_PASSWORD, 20000);
    }

    while (true) {
        if (adc_sampler_collect_batch(s_samples, sizeof(s_samples)) == ESP_OK) {
            post_capture(s_samples, SAMPLES_PER_BATCH);
            int sum = 0;
            for (size_t i = 0; i < SAMPLES_PER_BATCH; ++i) {
                sum += s_samples[i];
            }
            ESP_LOGI(TAG, "Capture posted successfully, sum of samples: %d", sum);
        }
    }
}

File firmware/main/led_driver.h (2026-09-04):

#ifndef LED_DRIVER_H
#define LED_DRIVER_H

#include <stddef.h>
#include <stdint.h>

#include "esp_err.h"
#include "iot_hub_client.h"

#ifndef DATA_PIN
#define DATA_PIN 4
#endif

#ifndef NUM_LEDS
#define NUM_LEDS 8
#endif

#ifndef BRIGHTNESS
#define BRIGHTNESS 128
#endif

#define LED_DATA_PIN DATA_PIN
#define LED_NUM_LEDS NUM_LEDS
#define LED_BRIGHTNESS BRIGHTNESS

typedef struct {
    uint8_t red;
    uint8_t green;
    uint8_t blue;
} led_rgb_t;

// Initialize the WS2812B strip and clear it.
esp_err_t led_driver_init(void);

// Set a pixel in the pending frame. Out-of-range indices are ignored.
void led_driver_set_pixel(size_t index, led_rgb_t color);

// Set the pending frame to one RGB color.
void led_driver_set_color(led_rgb_t color);

// Clear the pending frame.
void led_driver_clear(void);

// Transmit the pending frame only when it has changed.
esp_err_t led_driver_show(void);

// Set global brightness, clamped to 0-255.
void led_driver_set_brightness(uint16_t brightness);

// Set LED pattern based on device status.
void led_driver_set_status(device_operational_status_t status);

// Convert status string from backend to enum (returns STATUS_OFFLINE for unknown).
device_operational_status_t led_driver_status_from_string(const char *status_str);

// Turn LED off and stop the status pattern.
void led_driver_off(void);

#endif

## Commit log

2024-09-25 Added other files
    [base.3mf, base.blend, base.stl]
2024-09-25 Got some things working with the pi
    [base.3mf, base.blend, base.stl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]
2024-09-25 Added raspberry pi serial
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2024-09-26 Added AI to the raspberry pi
2024-10-09 Updated Model
    [base.3mf, base.blend, base.stl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]
2024-10-09 Create Bishop_ALotSmarter_Purchase Request.xlsx
    [Bishop_ALotSmarter_Purchase Request.xlsx]
2024-10-19 Added wifi helper (ability to set esp32 wifi creds)
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2024-11-07 Added notifications API
    [Bishop_ALotSmarter_Purchase Request.xlsx]
2024-11-12 Added base_core
    [base.blend, base.stl, base_core.stl]
2024-11-13 pushing pi code
    [base.3mf, base.blend, base.stl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]
2024-11-20 Connected "Toggle" Signal with slot. Re-arranged directory to have main.qml and main.pi in the same folder
2024-12-18 Create vcpkg
    [base.stl, base_core.stl]
2025-02-06 Added ability to connect device to the internet
2025-02-06 Big clean
    [Bishop_ALotSmarter_Purchase Request.xlsx, base.stl, base_core.stl]
2025-10-23 Remove unused capture and classify files; add MQTT broker and main connection logic
    [main.py]
2026-02-22 Add signs/events/notifications APIs and services
    Introduce full support for signs, events and notifications across backend and frontend. Added new FastAPI routers (events, notifications, signs) and wired them into main.py. Implemented service layer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
2026-02-23 Add hardware client and inference debug graph
    Add MicroPython hardware client and sensor/wifi utilities to sample a photoresistor and POST 512-sample batches to the inference endpoint. Enhance backend inference route to accept/rename signal->sam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
2026-03-02 Add refresh tokens, sign workflows, and WiFi setup
    Implement refresh-token support and end-to-end sign assistance workflow, plus device provisioning UI and client polyfills.
    Backend: include mobile redirect state in /auth/login and /auth/callback, return refreshToken from /auth/exchange and add POST /auth/refresh; tolerate clock skew in JWT verification; normalize router prefixes (remove trailing slashes) and add redirect_slashes=False. Add inference-side logic to update sign status and create events/notifications on positive classifications. Extend signs API with new statuses (assistance_requested, assistance_in_progress) and add /signs/{id}/acknowledge and /signs/{id}/resolve endpoints. R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
    [main.py]
2026-03-30 Add production infrastructure and fix landing screen route
    - Fix LandingScreen deep linking to serve at root path (/)
    - Add nginx, terraform, and docker-compose production config
    - Update frontend dockerfile for static web export
    - Add WorkOS test keys to terraform.tfvars (gitignored)
    - Gitignore secrets: terraform.tfvars, tfstate, certs, .env.cert
2026-03-30 fix: resolve SSL, API URL, and missing dependency issues for local and production Docker
    - Add --trusted-host flags in Dockerfile for corporate proxy SSL bypass
    - Add pyperclip to requirements.txt (missing dependency)
    - Fix frontend API client to use EXPO_PUBLIC_API_URL env var with /api/v1 default instead of hardcoded LAN IP
    - Add SSL bypass for corporate proxy environments in backend (main.py, auth.py)
    - Update docker-compose.yml CORS_ORIGIN to match production pattern
    [main.py]
2026-03-30 feat: add organizations with RBAC
    - Add organizations and organization_members tables with org_role enum (owner/admin/member)
    - Add organization_id FK to signs table, user_id FK to notifications table
    - Create organization service and routes with full CRUD + member management
    - Scope sign listing to user's org memberships
    - Fan out notifications to all org members on wave detection, acknowledge, and resolve
    - Scope notification queries to authenticated user
    - Add organization API, Zustand store, and management screen to frontend
    - Add Orgs navigation button to HomeScreen header
    [main.py]
2026-04-27 feat: rebrand to Hazard Hero, add push notifications, fix bugs, integrate Montserrat font
    - Rebrand from Smart Handicap Sign to Hazard Hero across all files
    - Add push notification support (Expo Push API, backend + frontend)
    - Fix GET /signs/me route ordering, ADC 12-bit normalization, seed data
    - Replace SF Pro with Montserrat font family
    - Add custom app icons and splash screen
    - Add new screens: FeedbackScreen, SetupGuideScreen
    - Create Expo project @deploy-box/hazard-hero
    - Add nginx dev proxy config
    - Add backend security tests
    [main.py]
2026-05-02 refactor(frontend): migrate from signs API to v2 devices API
    - HomeScreen: use devicesAPI.list() instead of signAPI.getSigns(),
    display Device data (serial_number, lifecycle_status, updated_at),
    replace SignStatus STATUS_CONFIG with DeviceLifecycleStatus values,
    remove acknowledge/resolve sign action buttons, navigate to
    DeviceDetail instead of SignDetail
    - navigation.ts: remove SignDetail route, keep DeviceDetail route
    - RootNavigator: remove SignDetailScreen import and registration
    - api/api.ts: remove entire signAPI export (dead endpoint)
    - types/types.ts: remove Sign and SignStatus types (keep SignNotification)
    - Delete SignDetailScreen.tsx (replaced by existing DeviceDetailScree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
2026-05-11 feat: add ESP-IDF firmware (MicroPython to C migration)
    Migrate hardware firmware from MicroPython to C/ESP-IDF targeting
    ESP32-WROOM-32 for production use. Provides ~3x more free RAM
    (~150-200KB vs ~50-80KB), OTA updates, HTTPS with TLS, and
    deterministic memory management.
    Modules:
    - nvs_storage: NVS persistence for serial number, WiFi creds, auth token
    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
    [partitions.csv]
2026-05-13 feat: Add tasks for ESP-IDF firmware runtime development
    - Introduced a comprehensive task list for the ESP-IDF firmware runtime project, organized by phases and user stories.
    - Phase 1 focuses on setup and baseline confirmation of current behaviors across firmware, backend, and database schemas.
    - Phase 2 establishes foundational contracts and data, ensuring stability before user story implementation.
    - User Story 1 emphasizes provisioning device connectivity, while User Story 2 targets gesture sample detection and submission.
    - User Story 3 aims to maintain field runtime resilience against various failures.
    - Included cross-cutting hardening and polish tasks, along with validation gates to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
    [main.py]
2026-05-20 feat: Add E2E firmware mocks for testing without hardware
    - Created a new specification for end-to-end testing of firmware mocks to validate device-triggered workflows without physical ESP32.
    - Updated Terraform configuration to support Azure Container Apps, including key vault integration for secrets management.
    - Removed legacy VM and network configurations to streamline deployment.
    - Added necessary variables and outputs for the new infrastructure setup.
    - Updated the Terraform lock file to use the latest AzureRM provider version.
2026-05-20 chore: update deployment pipeline and database tooling
    Rename the deploy workflow to a generic CI/CD pipeline, run database migrations before Terraform applies infrastructure changes, and align the Azure deployment flow with Key Vault access updates. Als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
2026-05-26 Remove legacy MicroPython files and add solar power feasibility research document
    - Deleted `provision.py` and `sensor.py` as they are no longer needed.
    - Added `solar-power-research.md` to outline the feasibility of solar power integration for the Hazard Hero sign node, detailing current architecture, required changes, and risks.
    - Removed `wifi_utils.py` as it is obsolete in the current firmware structure.
    [main.py]
2026-05-27 refactor: remove unused types and update TypeScript configuration
    - Removed `SignNotification` type from `types.ts` as it is no longer needed.
    - Updated `tsconfig.json` to include "DOM" in the library list and excluded additional test files from compilation.
    - Cleaned up `pnpm-lock.yaml` by removing deprecated and unused dependencies, including several Expo-related packages and socket.io packages.
    [partitions.csv]
2026-05-28 Refactor provisioning flow and security measures for pilot mode
    - Update `/configure` endpoint to accept Wi-Fi credentials without requiring a setup or claim code during pilot provisioning.
    - Modify validation logic to reject malformed or oversized JSON payloads and ensure Wi-Fi credentials are saved only after successful requests.
    - Adjust documentation to reflect changes in provisioning behavior, including removal of setup/claim code requirements and updates to error handling.
    - Enhance accessibility requirements for Wi-Fi input fields and error messages in the frontend.
    - Revise observability and logging practices to ensure sensitive information is not exposed during provisioning attempts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
2026-06-01 feat: implement connectivity status tracking and sweep mechanism
    - Added connectivity_status field to devices for tracking online/offline status.
    - Implemented a periodic connectivity sweep to mark stale online devices as offline.
    - Enhanced device status responses to include connectivity status.
    - Updated device service methods to handle connectivity status transitions.
    - Created new notifications for device offline events.
    - Added tests for connectivity sweep functionality and device status routes.
    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
2026-06-02 Add tests for device service live updates, mobile updates, and notification service
    - Implement tests for device status transitions and assistance request handling in `test_device_service_live_updates.py`.
    - Create tests for mobile home updates and notification forwarding in `test_mobile_updates.py`.
    - Add comprehensive tests for notification service SQL helpers in `test_notification_service.py`.
    - Introduce an audio alert for assistance notifications with tests in `assistanceAlertSound.test.ts`.
    - Update HomeScreen to manage live updates and play alert sounds based on notification state.
    - Add support for audio file imports in Jest configuration and create a mock for audio files.
    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
2026-06-13 Add DPS client implementation and refactor IoT Hub client for X.509 authentication
    - Introduced dps_client.h and dps_client.c for device provisioning service (DPS) registration using X.509 certificates.
    - Removed https_client.c and https_client.h as they are no longer needed.
    - Updated iot_hub_client.c and iot_hub_client.h to support X.509 authentication, including client certificate and key management.
    - Modified main.c to load device identity from DPS and initialize IoT Hub client accordingly.
    - Enhanced NVS storage functions to save and load DPS assignment data.
    - Added a mock Python script for testing DPS registration and telemetry sending with X.509 credentials.
    [main.c, mock_dps_x509_device.py]
2026-06-28 feat: implement hazard-hero-esp32 extension for firmware management - Added extension for building, flashing, and capturing logs for ESP32 firmware. - Updated settings for IoT Hub connection and adde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
2026-07-01 Add WiFi Manager and Boot Support for Enhanced Connectivity
    - Implemented a new WiFi Manager (wifi_manager.c and wifi_manager.h) to handle WiFi connections, including station and access point modes, scanning for available networks, and managing connection states.
    - Introduced Boot Support functions (boot_support.c and boot_support.h) to manage device boot processes, including entering provisioning mode and handling fatal errors with appropriate logging and LED status updates.
    - Created Cloud Settings (cloud_settings.c and cloud_settings.h) to resolve IoT Hub settings using DPS for device registration.
    - Developed Identity Service (identity_service.c and identity_service.h) to manage device s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
    [adc_sampler.c]
2026-07-07 feat: add cacheLife type definitions and related functions for Next.js caching strategies
    - Introduced `unstable_cacheLife` function with various profiles (default, seconds, minutes, hours, days, weeks, max) for flexible caching configurations.
    - Added type definitions for cache-related exports in `next/cache`.
    chore: create package.json for type definitions in Next.js
    - Added a new `package.json` file to define module type for TypeScript compatibility.
    feat: generate routes type definitions for Next.js application
    - Created `routes.d.ts` to define application routes and their parameters for type safety.
    chore: implement validator for page and layout types in Next.js
    - Added `validator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
    [pitch_iphone.blend]
2026-09-02 feat: implement device twin service and integrate with device acknowledgment and status updates
2026-09-03 feat: Refactor HomePage component to enhance device management and status handling
    - Updated the HomePage component to utilize the new hazardHeroApi for device management.
    - Implemented device polling with a defined interval for real-time updates.
    - Added sound alert functionality for assistance requests.
    - Improved error handling and loading states.
    - Enhanced UI with metrics and improved layout for better user experience.
    chore: Update package.json to specify hostname for development server
    - Changed the development script to include hostname configuration for local development.
    refactor: Simplify API client implementation
    - Replaced Axios with Fetch API for making requests.
    - Streamli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
    [main.py]
2026-09-04 feat: integrate LED strip driver and enhance LED control functionality
    - Added support for WS2812B LED strip in the LED driver.
    - Updated CMakeLists.txt to include the led_strip component.
    - Modified idf_component.yml to add led_strip dependency.
    - Refactored led_driver.c to manage LED patterns and states using the new led_strip API.
    - Introduced functions for setting individual pixels, colors, and brightness.
    - Improved synchronization with FreeRTOS semaphores for thread safety.
    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
    [HH.blend, HazardHero-Enclosure Cover Left.3mf, HazardHero-Enclosure Left.3mf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]
